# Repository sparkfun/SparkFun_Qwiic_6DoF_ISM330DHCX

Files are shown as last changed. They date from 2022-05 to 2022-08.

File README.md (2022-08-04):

SparkFun Qwiic 6DoF ISM330DHCX
========================================

<table class="table table-hover table-striped table-bordered">
  <tr align="center">
   <td><a href="https://www.sparkfun.com/products/19764">SparkFun Qwiic 6DoF - ISM330DHCX (SEN-19764)</a></td>
   <td><a href="https://www.sparkfun.com/products/20176">SparkFun Micro 6DoF IMU - ISM330DHCX (Qwiic) (SEN-20176</a></td>
  </tr>
  <tr align="center">
   <td><i>SparkFun Qwiic 6DoF - ISM330DHCX [<a href="https://www.sparkfun.com/products/19764">SEN-19764</a>]</i></td>
   <td><i>SparkFun Micro 6DoF IMU - ISM330DHCX (Qwiic) [<a href="https://www.sparkfun.com/products/20176">SEN-20176</a>]</i></td>
  </tr>
</table>

Do you need 6 degrees of freedom? We do! Behold the SparkFun Qwiic 6DoF - ISM330DHCX - a Qwiic enabled 1x1" breakout featuring STMicroelectronics' ISM330DHCX; a high-performance 3D digital accelerometer and 3D digital gyroscope tailored for Industry 4.0 applications such as platform, optical image, and lens stabilization, robotics and industrial automation, navigations systems, and vibration monitoring and compensation. 

This bad boy has a full-scale acceleration range of ±2/±4/±8/±16 g and a wide angular rate range of ±125/±250/±500/±1000/±2000/±4000 dps that enable its usage in a broad range of applications. Multiple modes allow for peripheral only, secondary I<sup>2</sup>C, and and auxiliary 3 or 4 wire serial interface. An unmatched set of embedded features (Machine Learning Core, programmable FSM, FIFO, sensor hub, event decoding and interrupts) are enablers for implementing smart and complex sensor nodes which deliver high performance at very low power.  

The dual Qwiic connectors on this little breakout make setting it up a breeze. Simply supply the accelerometer with power and communication via the Qwiic connector to your chosen Qwiic development board and you will be good to go. Should you prefer to use them, we've also broken out all the ISM330DHCX pin functionality to GPIO along either side of the board. 

Repository Contents
-------------------

* **/Documentation** - Data sheets, additional product information
* **/Hardware** - Eagle design files (.brd, .sch)
* **/Production** - Production panel files (.brd)

Documentation
--------------

* **[Library](https://github.com/sparkfun/SparkFun_6DoF_ISM330DHCX_Arduino_Library)** - Arduino library for the SparkFun Qwiic 6DoF - ISM330DHCX.
* **[Hookup Guide](https://sparkle.sparkfun.com/sparkle/learn_tutorials/2484)** - Basic hookup guide for the SparkFun Qwiic 6DoF - ISM330DHCX.

Product Versions
--------------

* [SEN-20176](https://www.sparkfun.com/products/20176) - SparkFun red version, micro size
* [SEN-19764](https://www.sparkfun.com/products/19764) - SparkFun red version

License Information
-------------------

This product is _**open source**_! 

Please review the LICENSE.md file for license information. 

If you have any questions or concerns on licensing, please contact technical support on our [SparkFun forums](https://forum.sparkfun.com/viewforum.php?f=152).

Distributed as-is; no warranty is given.

- Your friends at SparkFun.

_<COLLABORATION CREDIT>_

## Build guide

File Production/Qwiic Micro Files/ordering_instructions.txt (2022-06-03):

panel size, 170x79mm
PCB thickness, 1.6mm
number of layers, 2
soldermask color, Red
silkscreen color, White
oz copper, 1oz
finish, HASL lead free
stencils, top
pcs per panel, 64
min trace width, 0.1524mm / 0.0060in
min drill size, 0.3000mm / 0.0118in

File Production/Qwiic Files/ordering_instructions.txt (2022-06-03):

panel size, 169x117mm
PCB thickness, 1.6mm
number of layers, 2
soldermask color, Red
silkscreen color, White
oz copper, 1oz
finish, HASL lead free
stencils, top
pcs per panel, 24
min trace width, 0.2540mm / 0.0100in
min drill size, 0.3000mm / 0.0118in

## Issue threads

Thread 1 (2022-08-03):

SparkFun Micro 6DoF IMU - ISM330DHCX (Qwiic): adding "stamp type" pins? (general for all micro boards)

jerabaul29, 2022-08-03:
Thanks for amazing boards as usual :) . A small thought: would it be possible to actually break out the key pins on the chip (power, I2C, maybe interrupts and a couple more, you can evaluate which may be most valuable for different uses :) ) on the breakout board, possibly as "side stamp type pins" if there is no space to put through holes pin holes? I.e., something similar to for example:

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

This comment would be applicable to all "Micro" breakouts. The advantage then is that the "Micro" boards could also be soldered on a master PCB easily if wanted, extending possibilities of use.

edspark, 2022-08-03:
Thank you for the suggestion! We had a discussion while developing the Qwiic Micro about exactly this. We decided against it in the end, but if we see a strong desire for this addition we'll definitely revisit it.

jerabaul29, 2022-08-03:
Thanks for the explanation :) . Just curious, what were the cons Vs pros on this? I only see pros, but certainly missing something :) .

edspark, 2022-08-03:
We wanted the smallest board we could manage and those castellated leads ("side stamp type pins" as you called them) eat into the design space quite a bit.  We would have ended up with a larger PCB then we were shooting for.

jerabaul29, 2022-08-03:
Understand, thanks :) .

Closed 2022-08-03.

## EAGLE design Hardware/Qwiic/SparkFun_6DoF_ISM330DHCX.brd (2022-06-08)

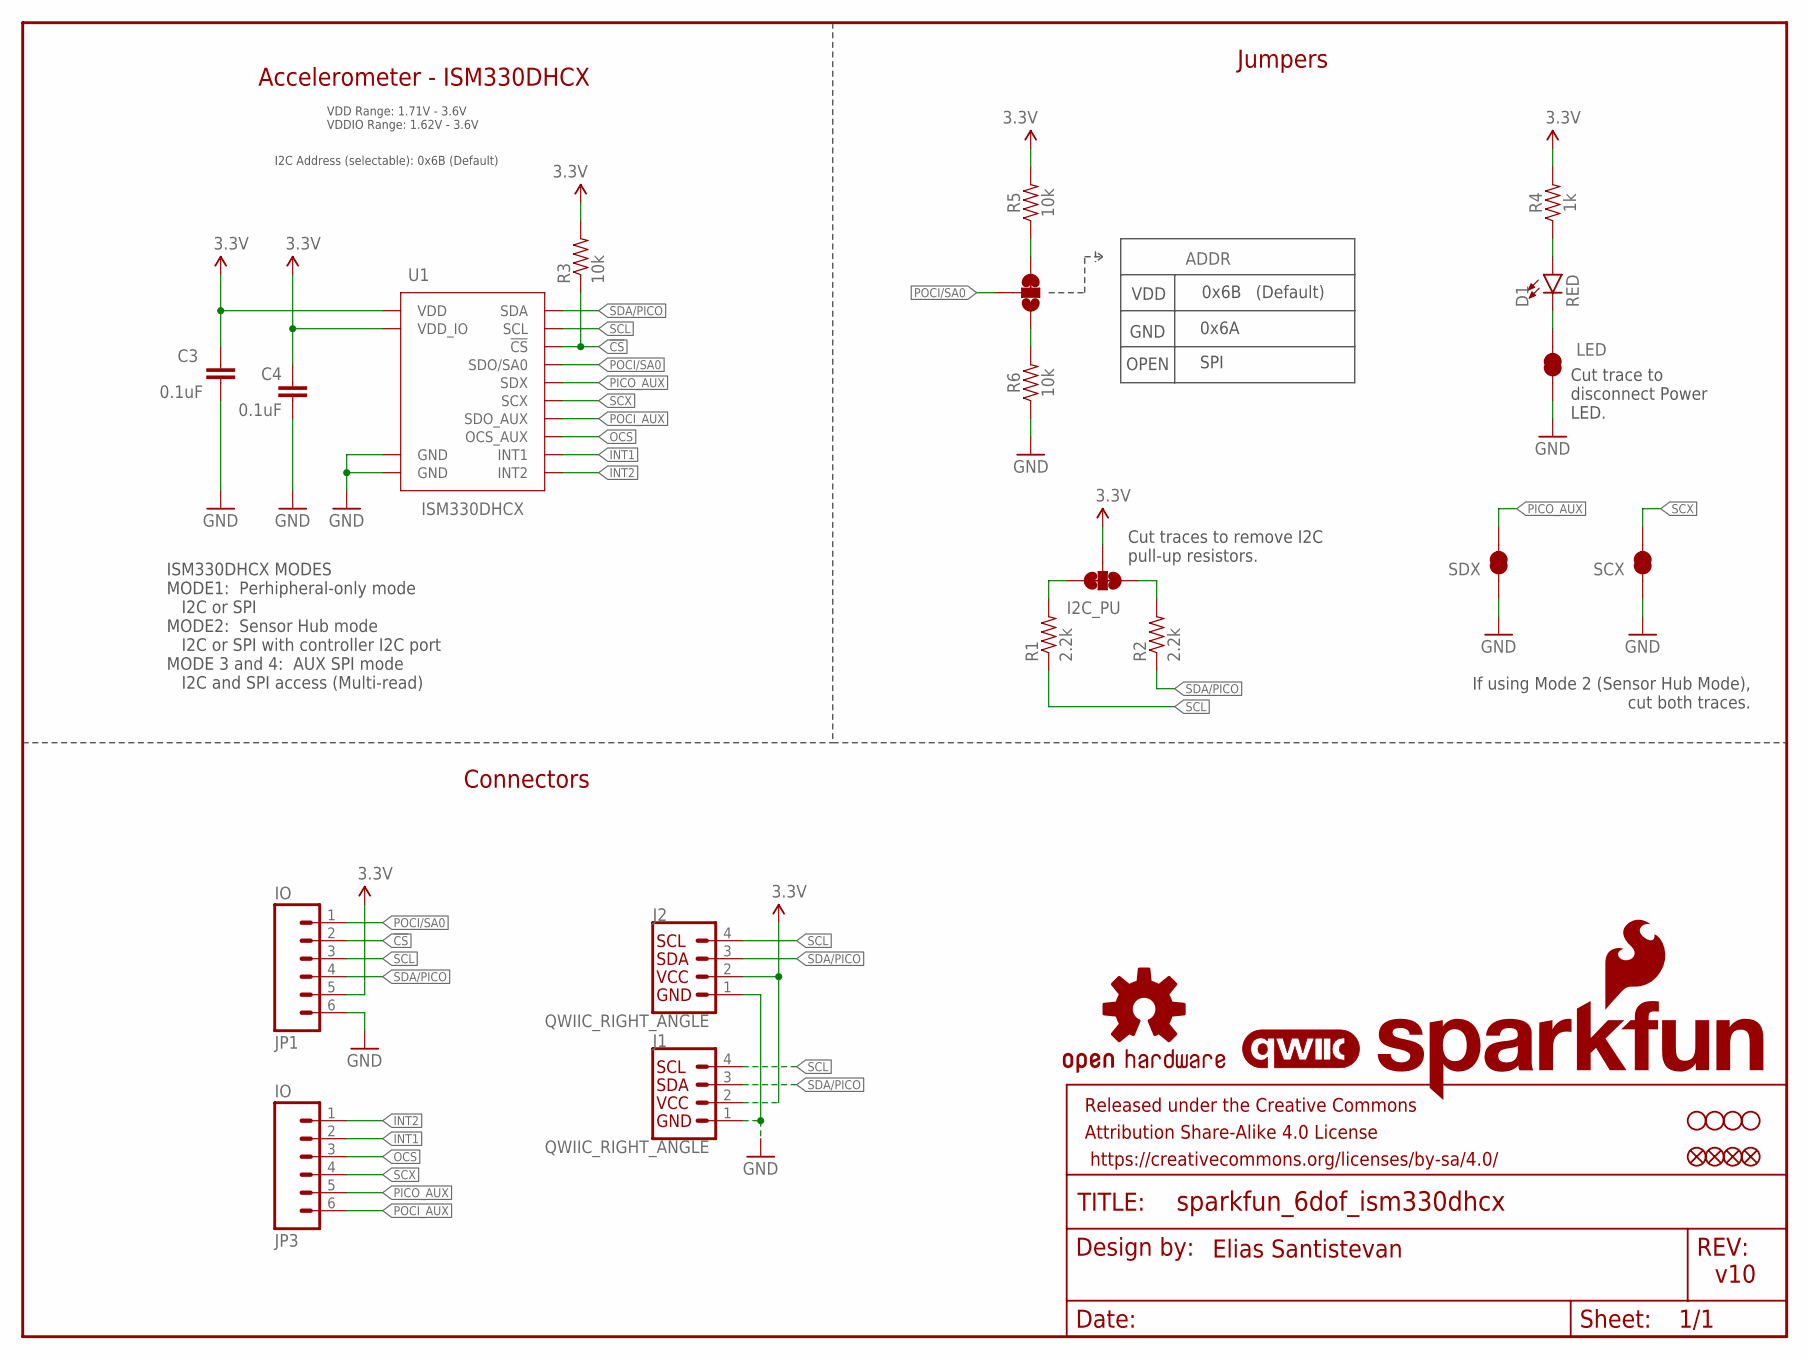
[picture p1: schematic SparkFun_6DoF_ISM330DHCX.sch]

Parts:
ADDR: JUMPER-SMT_3_1-NC_TRACE_SILK; SMT-JUMPER_3_1-NC_TRACE_SILK
C3, C4: 0.1uF; 0603
D1: RED; LED-0603
FD1, FD2: FIDUCIALUFIDUCIAL; FIDUCIAL-MICRO
FID1, FID2: FIDUCIALUFIDUCIAL; FIDUCIAL-MICRO
FRAME1: FRAME-LETTER; CREATIVE_COMMONS
I2C_PU: S_MODE; SMT-JUMPER_3_2-NC_TRACE_SILK
J1, J2: QWIIC_RIGHT_ANGLE; JST04_1MM_RA
JP1, JP3: IO; 1X06_NO_SILK
LED: JUMPER-SMT_2_NC_TRACE_SILK; SMT-JUMPER_2_NC_TRACE_SILK
LOGO1: QWIIC_LOGO_4MM; QWIIC_4MM
LOGO2: OSHW-LOGOMINI; OSHW-LOGO-MINI
LOGO3: SFE_LOGO_NAME_FLAME.1_INCH; SFE_LOGO_NAME_FLAME_.1
R1, R2: 2.2k; 0603
R3, R5, R6: 10k; 0603
R4: 1k; 0603
SCX: JUMPER-SMT_2_NC_TRACE_SILK; SMT-JUMPER_2_NC_TRACE_SILK
SDX: JUMPER-SMT_2_NC_TRACE_SILK; SMT-JUMPER_2_NC_TRACE_SILK
STANDOFF1, STANDOFF2, STANDOFF3, STANDOFF4: STAND-OFFTIGHT; STAND-OFF-TIGHT
U1: ISM330DHCX; LGA-14L

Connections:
3.3V: C3.1, C4.1, I2C_PU.2, J1.2, J2.2, JP1.5, R3.2, R4.2, R5.2, U1.P5 (VDD_IO), U1.P8 (VDD)
!CS!: JP1.2, R3.1, U1.P12 (!CS!)
GND: C3.2, C4.2, J1.1, J2.1, JP1.6, LED.1, R6.1, SCX.1, SDX.1, U1.P6 (GND), U1.P7 (GND)
INT1: JP3.2, U1.P4 (INT1)
INT2: JP3.1, U1.P9 (INT2)
unnamed: ADDR.3, R5.1
unnamed: D1.A, R4.1
unnamed: D1.C, LED.2
unnamed: I2C_PU.1, R1.2
unnamed: I2C_PU.3, R2.2
unnamed: ADDR.1, R6.2
OCS: JP3.3, U1.P10 (OCS_AUX)
PICO_AUX: JP3.5, SDX.2, U1.P2 (SDX)
POCI/SA0: ADDR.2, JP1.1, U1.P1 (SDO/SA0)
POCI_AUX: JP3.6, U1.P11 (SDO_AUX)
SCL: J1.4, J2.4, JP1.3, R1.1, U1.P13 (SCL)
SCX: JP3.4, SCX.2, U1.P3 (SCX)
SDA/PICO: J1.3, J2.3, JP1.4, R2.1, U1.P14 (SDA)

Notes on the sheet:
Accelerometer - ISM330DHCX
If using Mode 2 (Sensor Hub Mode), cut both traces.
Cut traces to remove I2C pull-up resistors.
ISM330DHCX MODES MODE1: Perhipheral-only mode I2C or SPI MODE2: Sensor Hub mode I2C or SPI with controller I2C port MODE 3 and 4: AUX SPI mode I2C and SPI access (Multi-read)
VDD Range: 1.71V - 3.6V VDDIO Range: 1.62V - 3.6V
v10
Jumpers
Cut trace to disconnect Power LED.
Connectors
VDD
GND
OPEN
0x6B
0x6A
SPI
Elias Santistevan
(Default)
I2C Address (selectable): 0x6B (Default)

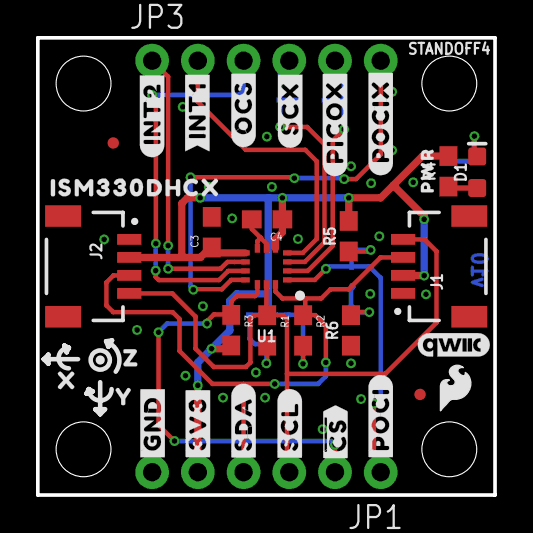
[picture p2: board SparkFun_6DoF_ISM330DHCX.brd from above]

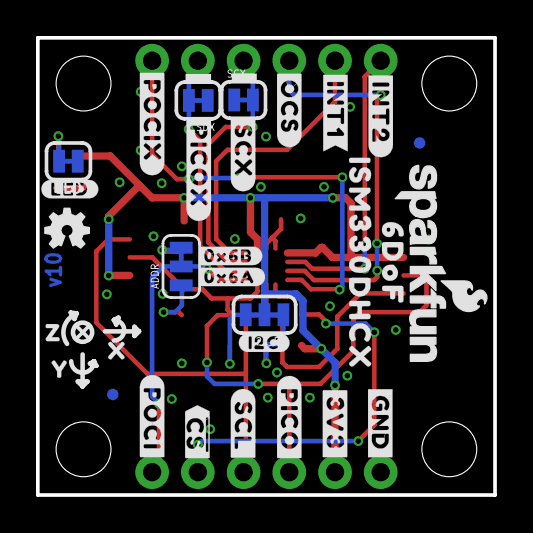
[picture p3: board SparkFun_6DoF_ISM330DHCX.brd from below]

Board: 2 copper layers, 25.4 x 25.4 mm, 70 parts (30 on the bottom side), 18 nets.

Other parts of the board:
U$1, U$15: #3V3#1
U$2, U$17: #GND#0
U$3: ##CS##7
U$4: #SDA#4
U$5, U$22: #SCL#5
U$6: #POCI#11
U$7, U$19: #INT1#9
U$8: #INT2#2
U$9: #OCS#8
U$10: #SCX#9
U$11: #PICOX#10
U$12: ISM330DHCX331
U$13: #0X6A#11
U$14: #0X6B#11
U$16: #LED#11
U$18: #POCI#12
U$20: #OCS#7
U$23: #SCX#8
U$24: #POCIX#8
U$25: #I2C#11
U$26: #PICO#13
U$27: ##CS##8
U$28: PWR8
U$29: SFE_LOGO_FLAME_.1
U$30: ISM330DHCX20
U$31: 6DOF12
U$32: #PICOX#9
U$33: #POCIX#7
U$34, U$37: X2114
U$35, U$38: Y2115
U$36, U$39: Z2116
U$40: #INT2#3

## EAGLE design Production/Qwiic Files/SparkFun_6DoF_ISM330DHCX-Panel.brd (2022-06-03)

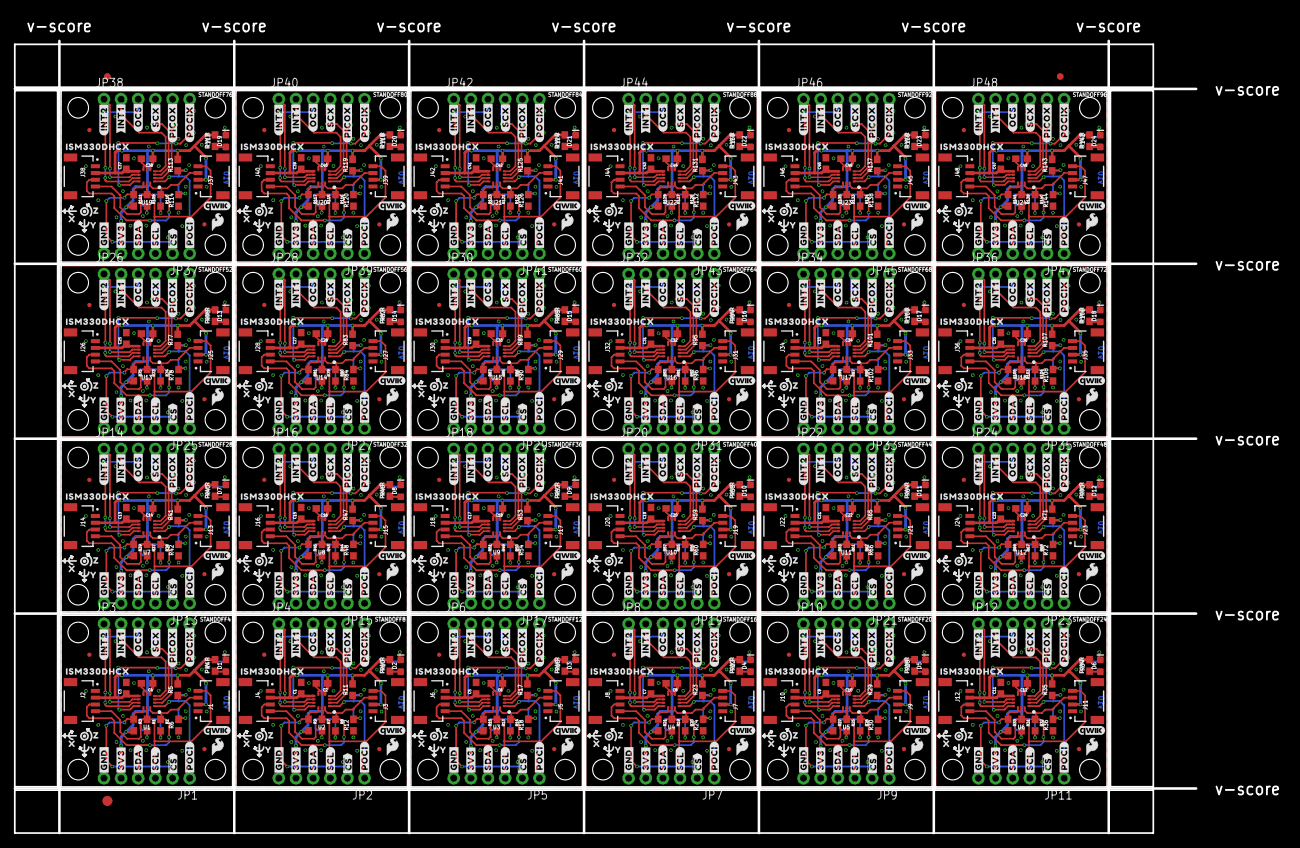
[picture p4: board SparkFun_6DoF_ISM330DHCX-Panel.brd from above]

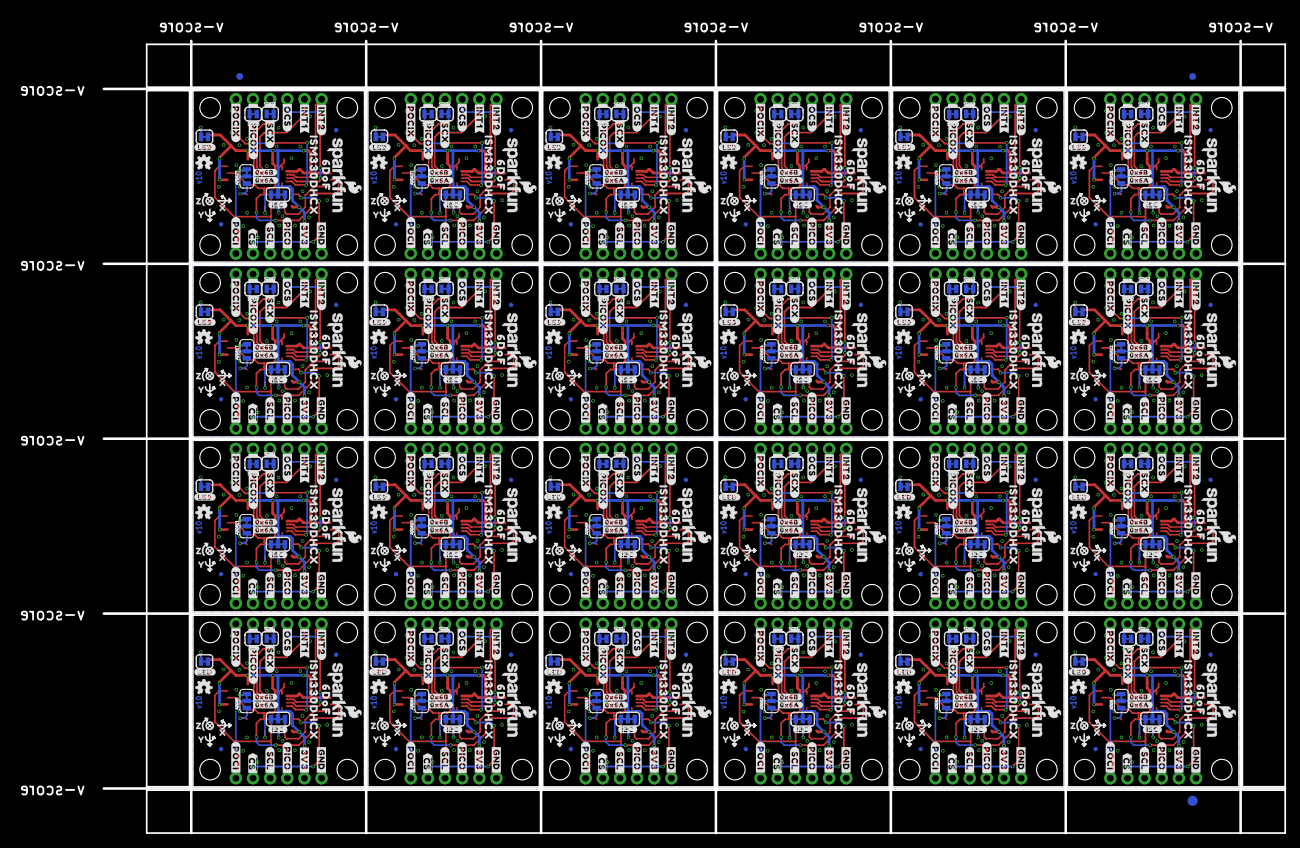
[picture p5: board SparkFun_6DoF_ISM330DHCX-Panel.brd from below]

Board: 2 copper layers, 175.0 x 117.3 mm, 1662 parts (723 on the bottom side), 432 nets.

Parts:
ADDR, ADDR1, ADDR2, ADDR3, ADDR4, ADDR5, ADDR6, ADDR7, ADDR8, ADDR9, ADDR10, ADDR11, ADDR12, ADDR13, ADDR14, ADDR15, ADDR16, ADDR17, ADDR18, ADDR19, ADDR20, ADDR21, ADDR22, ADDR23: JUMPER-SMT_3_1-NC_TRACE_SILK; SMT-JUMPER_3_1-NC_TRACE_SILK
C1, C2, C3, C4, C5, C6, C7, C8, C9, C10, C11, C12, C13, C14, C15, C16, C17, C18, C19, C20, C21, C22, C23, C24, C25, C26, C27, C28, C29, C30, C31, C32, C33, C34, C35, C36, C37, C38, C39, C40, C41, C42, C43, C44, C45, C46, C47, C48: 0.1uF; 0603
D1, D2, D3, D4, D5, D6, D7, D8, D9, D10, D11, D12, D13, D14, D15, D16, D17, D18, D19, D20, D21, D22, D23, D24: RED; LED-0603
E$1, E$2, E$3, E$4: FIDUCIAL-1X2
E$5, E$6: FIDUCIAL-1.5X3
FD1, FD2, FD3, FD4, FD5, FD6, FD7, FD8, FD9, FD10, FD11, FD12, FD13, FD14, FD15, FD16, FD17, FD18, FD19, FD20, FD21, FD22, FD23, FD24, FD25, FD26, FD27, FD28, FD29, FD30, FD31, FD32, FD33, FD34, FD35, FD36, FD37, FD38, FD39, FD40, FD41, FD42, FD43, FD44, FD45, FD46, FD47, FD48: FIDUCIALUFIDUCIAL; FIDUCIAL-MICRO
FID1, FID2, FID3, FID4, FID5, FID6, FID7, FID8, FID9, FID10, FID11, FID12, FID13, FID14, FID15, FID16, FID17, FID18, FID19, FID20, FID21, FID22, FID23, FID24, FID25, FID26, FID27, FID28, FID29, FID30, FID31, FID32, FID33, FID34, FID35, FID36, FID37, FID38, FID39, FID40, FID41, FID42, FID43, FID44, FID45, FID46, FID47, FID48: FIDUCIALUFIDUCIAL; FIDUCIAL-MICRO
I2C_PU, I2C_PU1, I2C_PU2, I2C_PU3, I2C_PU4, I2C_PU5, I2C_PU6, I2C_PU7, I2C_PU8, I2C_PU9, I2C_PU10, I2C_PU11, I2C_PU12, I2C_PU13, I2C_PU14, I2C_PU15, I2C_PU16, I2C_PU17, I2C_PU18, I2C_PU19, I2C_PU20, I2C_PU21, I2C_PU22, I2C_PU23: S_MODE; SMT-JUMPER_3_2-NC_TRACE_SILK
J1, J2, J3, J4, J5, J6, J7, J8, J9, J10, J11, J12, J13, J14, J15, J16, J17, J18, J19, J20, J21, J22, J23, J24, J25, J26, J27, J28, J29, J30, J31, J32, J33, J34, J35, J36, J37, J38, J39, J40, J41, J42, J43, J44, J45, J46, J47, J48: QWIIC_RIGHT_ANGLE; JST04_1MM_RA
JP1, JP2, JP3, JP4, JP5, JP6, JP7, JP8, JP9, JP10, JP11, JP12, JP13, JP14, JP15, JP16, JP17, JP18, JP19, JP20, JP21, JP22, JP23, JP24, JP25, JP26, JP27, JP28, JP29, JP30, JP31, JP32, JP33, JP34, JP35, JP36, JP37, JP38, JP39, JP40, JP41, JP42, JP43, JP44, JP45, JP46, JP47, JP48: IO; 1X06_NO_SILK
LED, LED1, LED2, LED3, LED4, LED5, LED6, LED7, LED8, LED9, LED10, LED11, LED12, LED13, LED14, LED15, LED16, LED17, LED18, LED19, LED20, LED21, LED22, LED23: JUMPER-SMT_2_NC_TRACE_SILK; SMT-JUMPER_2_NC_TRACE_SILK
LOGO1, LOGO6, LOGO9, LOGO12, LOGO15, LOGO18, LOGO21, LOGO24, LOGO27, LOGO30, LOGO33, LOGO36, LOGO39, LOGO42, LOGO45, LOGO48, LOGO51, LOGO54, LOGO57, LOGO60, LOGO63, LOGO66, LOGO69, LOGO72: QWIIC_LOGO_4MM; QWIIC_4MM
LOGO2, LOGO4, LOGO7, LOGO10, LOGO13, LOGO16, LOGO19, LOGO22, LOGO25, LOGO28, LOGO31, LOGO34, LOGO37, LOGO40, LOGO43, LOGO46, LOGO49, LOGO52, LOGO55, LOGO58, LOGO61, LOGO64, LOGO67, LOGO70: OSHW-LOGOMINI; OSHW-LOGO-MINI
LOGO3, LOGO5, LOGO8, LOGO11, LOGO14, LOGO17, LOGO20, LOGO23, LOGO26, LOGO29, LOGO32, LOGO35, LOGO38, LOGO41, LOGO44, LOGO47, LOGO50, LOGO53, LOGO56, LOGO59, LOGO62, LOGO65, LOGO68, LOGO71: SFE_LOGO_NAME_FLAME.1_INCH; SFE_LOGO_NAME_FLAME_.1
R1, R2, R7, R8, R13, R14, R19, R20, R25, R26, R31, R32, R37, R38, R43, R44, R49, R50, R55, R56, R61, R62, R67, R68, R73, R74, R79, R80, R85, R86, R91, R92, R97, R98, R103, R104, R109, R110, R115, R116, R121, R122, R127, R128, R133, R134, R139, R140: 2.2k; 0603
R3, R5, R6, R9, R11, R12, R15, R17, R18, R21, R23, R24, R27, R29, R30, R33, R35, R36, R39, R41, R42, R45, R47, R48, R51, R53, R54, R57, R59, R60, R63, R65, R66, R69, R71, R72, R75, R77, R78, R81, R83, R84, R87, R89, R90, R93, R95, R96, R99, R101, R102, R105, R107, R108, R111, R113, R114, R117, R119, R120, R123, R125, R126, R129, R131, R132, R135, R137, R138, R141, R143, R144: 10k; 0603
R4, R10, R16, R22, R28, R34, R40, R46, R52, R58, R64, R70, R76, R82, R88, R94, R100, R106, R112, R118, R124, R130, R136, R142: 1k; 0603
SCX, SCX1, SCX2, SCX3, SCX4, SCX5, SCX6, SCX7, SCX8, SCX9, SCX10, SCX11, SCX12, SCX13, SCX14, SCX15, SCX16, SCX17, SCX18, SCX19, SCX20, SCX21, SCX22, SCX23: JUMPER-SMT_2_NC_TRACE_SILK; SMT-JUMPER_2_NC_TRACE_SILK
SDX, SDX1, SDX2, SDX3, SDX4, SDX5, SDX6, SDX7, SDX8, SDX9, SDX10, SDX11, SDX12, SDX13, SDX14, SDX15, SDX16, SDX17, SDX18, SDX19, SDX20, SDX21, SDX22, SDX23: JUMPER-SMT_2_NC_TRACE_SILK; SMT-JUMPER_2_NC_TRACE_SILK
STANDOFF1, STANDOFF2, STANDOFF3, STANDOFF4, STANDOFF5, STANDOFF6, STANDOFF7, STANDOFF8, STANDOFF9, STANDOFF10, STANDOFF11, STANDOFF12, STANDOFF13, STANDOFF14, STANDOFF15, STANDOFF16, STANDOFF17, STANDOFF18, STANDOFF19, STANDOFF20, STANDOFF21, STANDOFF22, STANDOFF23, STANDOFF24, STANDOFF25, STANDOFF26, STANDOFF27, STANDOFF28, STANDOFF29, STANDOFF30, STANDOFF31, STANDOFF32, STANDOFF33, STANDOFF34, STANDOFF35, STANDOFF36, STANDOFF37, STANDOFF38, STANDOFF39, STANDOFF40, STANDOFF41, STANDOFF42, STANDOFF43, STANDOFF44, STANDOFF45, STANDOFF46, STANDOFF47, STANDOFF48, STANDOFF49, STANDOFF50, STANDOFF51, STANDOFF52, STANDOFF53, STANDOFF54, STANDOFF55, STANDOFF56, STANDOFF57, STANDOFF58, STANDOFF59, STANDOFF60, STANDOFF61, STANDOFF62, STANDOFF63, STANDOFF64, STANDOFF65, STANDOFF66, STANDOFF67, STANDOFF68, STANDOFF69, STANDOFF70, STANDOFF71, STANDOFF72, STANDOFF73, STANDOFF74, STANDOFF75, STANDOFF76, STANDOFF77, STANDOFF78, STANDOFF79, STANDOFF80, STANDOFF81, STANDOFF82, STANDOFF83, STANDOFF84, STANDOFF85, STANDOFF86, STANDOFF87, STANDOFF88, STANDOFF89, STANDOFF90, STANDOFF91, STANDOFF92, STANDOFF93, STANDOFF94, STANDOFF95, STANDOFF96: STAND-OFFTIGHT; STAND-OFF-TIGHT
U1, U2, U3, U4, U5, U6, U7, U8, U9, U10, U11, U12, U13, U14, U15, U16, U17, U18, U19, U20, U21, U22, U23, U24: ISM330DHCX; LGA-14L
U$1, U$15, U$21, U$46, U$79, U$85, U$118, U$124, U$157, U$163, U$196, U$202, U$235, U$241, U$274, U$280, U$313, U$319, U$352, U$358, U$391, U$397, U$430, U$436, U$469, U$475, U$508, U$514, U$547, U$553, U$586, U$592, U$625, U$631, U$664, U$670, U$703, U$709, U$742, U$748, U$781, U$787, U$820, U$826, U$859, U$865, U$898, U$904: #3V3#1
U$2, U$17, U$41, U$47, U$80, U$86, U$119, U$125, U$158, U$164, U$197, U$203, U$236, U$242, U$275, U$281, U$314, U$320, U$353, U$359, U$392, U$398, U$431, U$437, U$470, U$476, U$509, U$515, U$548, U$554, U$587, U$593, U$626, U$632, U$665, U$671, U$704, U$710, U$743, U$749, U$782, U$788, U$821, U$827, U$860, U$866, U$899, U$905: #GND#0
U$3, U$58, U$97, U$136, U$175, U$214, U$253, U$292, U$331, U$370, U$409, U$448, U$487, U$526, U$565, U$604, U$643, U$682, U$721, U$760, U$799, U$838, U$877, U$916: ##CS##7
U$4, U$42, U$81, U$120, U$159, U$198, U$237, U$276, U$315, U$354, U$393, U$432, U$471, U$510, U$549, U$588, U$627, U$666, U$705, U$744, U$783, U$822, U$861, U$900: #SDA#4
U$5, U$22, U$43, U$49, U$82, U$88, U$121, U$127, U$160, U$166, U$199, U$205, U$238, U$244, U$277, U$283, U$316, U$322, U$355, U$361, U$394, U$400, U$433, U$439, U$472, U$478, U$511, U$517, U$550, U$556, U$589, U$595, U$628, U$634, U$667, U$673, U$706, U$712, U$745, U$751, U$784, U$790, U$823, U$829, U$862, U$868, U$901, U$907: #SCL#5
U$6, U$69, U$108, U$147, U$186, U$225, U$264, U$303, U$342, U$381, U$420, U$459, U$498, U$537, U$576, U$615, U$654, U$693, U$732, U$771, U$810, U$849, U$888, U$927: #POCI#11
U$7, U$19, U$56, U$57, U$95, U$96, U$134, U$135, U$173, U$174, U$212, U$213, U$251, U$252, U$290, U$291, U$329, U$330, U$368, U$369, U$407, U$408, U$446, U$447, U$485, U$486, U$524, U$525, U$563, U$564, U$602, U$603, U$641, U$642, U$680, U$681, U$719, U$720, U$758, U$759, U$797, U$798, U$836, U$837, U$875, U$876, U$914, U$915: #INT1#9
U$8, U$78, U$117, U$156, U$195, U$234, U$273, U$312, U$351, U$390, U$429, U$468, U$507, U$546, U$585, U$624, U$663, U$702, U$741, U$780, U$819, U$858, U$897, U$936: #INT2#2
U$9, U$44, U$83, U$122, U$161, U$200, U$239, U$278, U$317, U$356, U$395, U$434, U$473, U$512, U$551, U$590, U$629, U$668, U$707, U$746, U$785, U$824, U$863, U$902: #OCS#8
U$10, U$45, U$84, U$123, U$162, U$201, U$240, U$279, U$318, U$357, U$396, U$435, U$474, U$513, U$552, U$591, U$630, U$669, U$708, U$747, U$786, U$825, U$864, U$903: #SCX#9
U$11, U$64, U$103, U$142, U$181, U$220, U$259, U$298, U$337, U$376, U$415, U$454, U$493, U$532, U$571, U$610, U$649, U$688, U$727, U$766, U$805, U$844, U$883, U$922: #PICOX#10
U$12, U$62, U$101, U$140, U$179, U$218, U$257, U$296, U$335, U$374, U$413, U$452, U$491, U$530, U$569, U$608, U$647, U$686, U$725, U$764, U$803, U$842, U$881, U$920: ISM330DHCX331
U$13, U$52, U$91, U$130, U$169, U$208, U$247, U$286, U$325, U$364, U$403, U$442, U$481, U$520, U$559, U$598, U$637, U$676, U$715, U$754, U$793, U$832, U$871, U$910: #0X6A#11
U$14, U$53, U$92, U$131, U$170, U$209, U$248, U$287, U$326, U$365, U$404, U$443, U$482, U$521, U$560, U$599, U$638, U$677, U$716, U$755, U$794, U$833, U$872, U$911: #0X6B#11
U$16, U$51, U$90, U$129, U$168, U$207, U$246, U$285, U$324, U$363, U$402, U$441, U$480, U$519, U$558, U$597, U$636, U$675, U$714, U$753, U$792, U$831, U$870, U$909: #LED#11
U$18, U$70, U$109, U$148, U$187, U$226, U$265, U$304, U$343, U$382, U$421, U$460, U$499, U$538, U$577, U$616, U$655, U$694, U$733, U$772, U$811, U$850, U$889, U$928: #POCI#12
U$20, U$48, U$87, U$126, U$165, U$204, U$243, U$282, U$321, U$360, U$399, U$438, U$477, U$516, U$555, U$594, U$633, U$672, U$711, U$750, U$789, U$828, U$867, U$906: #OCS#7
U$23, U$50, U$89, U$128, U$167, U$206, U$245, U$284, U$323, U$362, U$401, U$440, U$479, U$518, U$557, U$596, U$635, U$674, U$713, U$752, U$791, U$830, U$869, U$908: #SCX#8
U$24, U$65, U$104, U$143, U$182, U$221, U$260, U$299, U$338, U$377, U$416, U$455, U$494, U$533, U$572, U$611, U$650, U$689, U$728, U$767, U$806, U$845, U$884, U$923: #POCIX#8
U$25, U$54, U$93, U$132, U$171, U$210, U$249, U$288, U$327, U$366, U$405, U$444, U$483, U$522, U$561, U$600, U$639, U$678, U$717, U$756, U$795, U$834, U$873, U$912: #I2C#11
U$26, U$68, U$107, U$146, U$185, U$224, U$263, U$302, U$341, U$380, U$419, U$458, U$497, U$536, U$575, U$614, U$653, U$692, U$731, U$770, U$809, U$848, U$887, U$926: #PICO#13
U$27, U$59, U$98, U$137, U$176, U$215, U$254, U$293, U$332, U$371, U$410, U$449, U$488, U$527, U$566, U$605, U$644, U$683, U$722, U$761, U$800, U$839, U$878, U$917: ##CS##8
U$28, U$55, U$94, U$133, U$172, U$211, U$250, U$289, U$328, U$367, U$406, U$445, U$484, U$523, U$562, U$601, U$640, U$679, U$718, U$757, U$796, U$835, U$874, U$913: PWR8
U$29, U$61, U$100, U$139, U$178, U$217, U$256, U$295, U$334, U$373, U$412, U$451, U$490, U$529, U$568, U$607, U$646, U$685, U$724, U$763, U$802, U$841, U$880, U$919: SFE_LOGO_FLAME_.1
U$30, U$63, U$102, U$141, U$180, U$219, U$258, U$297, U$336, U$375, U$414, U$453, U$492, U$531, U$570, U$609, U$648, U$687, U$726, U$765, U$804, U$843, U$882, U$921: ISM330DHCX20
U$31, U$60, U$99, U$138, U$177, U$216, U$255, U$294, U$333, U$372, U$411, U$450, U$489, U$528, U$567, U$606, U$645, U$684, U$723, U$762, U$801, U$840, U$879, U$918: 6DOF12
U$32, U$66, U$105, U$144, U$183, U$222, U$261, U$300, U$339, U$378, U$417, U$456, U$495, U$534, U$573, U$612, U$651, U$690, U$729, U$768, U$807, U$846, U$885, U$924: #PICOX#9
U$33, U$67, U$106, U$145, U$184, U$223, U$262, U$301, U$340, U$379, U$418, U$457, U$496, U$535, U$574, U$613, U$652, U$691, U$730, U$769, U$808, U$847, U$886, U$925: #POCIX#7
U$34, U$37, U$71, U$74, U$110, U$113, U$149, U$152, U$188, U$191, U$227, U$230, U$266, U$269, U$305, U$308, U$344, U$347, U$383, U$386, U$422, U$425, U$461, U$464, U$500, U$503, U$539, U$542, U$578, U$581, U$617, U$620, U$656, U$659, U$695, U$698, U$734, U$737, U$773, U$776, U$812, U$815, U$851, U$854, U$890, U$893, U$929, U$932: X2114
U$35, U$38, U$72, U$75, U$111, U$114, U$150, U$153, U$189, U$192, U$228, U$231, U$267, U$270, U$306, U$309, U$345, U$348, U$384, U$387, U$423, U$426, U$462, U$465, U$501, U$504, U$540, U$543, U$579, U$582, U$618, U$621, U$657, U$660, U$696, U$699, U$735, U$738, U$774, U$777, U$813, U$816, U$852, U$855, U$891, U$894, U$930, U$933: Y2115
U$36, U$39, U$73, U$76, U$112, U$115, U$151, U$154, U$190, U$193, U$229, U$232, U$268, U$271, U$307, U$310, U$346, U$349, U$385, U$388, U$424, U$427, U$463, U$466, U$502, U$505, U$541, U$544, U$580, U$583, U$619, U$622, U$658, U$661, U$697, U$700, U$736, U$739, U$775, U$778, U$814, U$817, U$853, U$856, U$892, U$895, U$931, U$934: Z2116
U$40, U$77, U$116, U$155, U$194, U$233, U$272, U$311, U$350, U$389, U$428, U$467, U$506, U$545, U$584, U$623, U$662, U$701, U$740, U$779, U$818, U$857, U$896, U$935: #INT2#3

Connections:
3.3V: C3.1, C4.1, I2C_PU.2, J1.2, J2.2, JP1.5, R3.2, R4.2, R5.2, U1.P5, U1.P8
3.3V1: C1.1, C2.1, I2C_PU1.2, J3.2, J4.2, JP2.5, R9.2, R10.2, R11.2, U2.P5, U2.P8
3.3V2: C5.1, C6.1, I2C_PU2.2, J5.2, J6.2, JP5.5, R15.2, R16.2, R17.2, U3.P5, U3.P8
3.3V3: C7.1, C8.1, I2C_PU3.2, J7.2, J8.2, JP7.5, R21.2, R22.2, R23.2, U4.P5, U4.P8
3.3V4: C9.1, C10.1, I2C_PU4.2, J9.2, J10.2, JP9.5, R27.2, R28.2, R29.2, U5.P5, U5.P8
3.3V5: C11.1, C12.1, I2C_PU5.2, J11.2, J12.2, JP11.5, R33.2, R34.2, R35.2, U6.P5, U6.P8
3.3V6: C13.1, C14.1, I2C_PU6.2, J13.2, J14.2, JP13.5, R39.2, R40.2, R41.2, U7.P5, U7.P8
3.3V7: C15.1, C16.1, I2C_PU7.2, J15.2, J16.2, JP15.5, R45.2, R46.2, R47.2, U8.P5, U8.P8
3.3V8: C17.1, C18.1, I2C_PU8.2, J17.2, J18.2, JP17.5, R51.2, R52.2, R53.2, U9.P5, U9.P8
3.3V9: C19.1, C20.1, I2C_PU9.2, J19.2, J20.2, JP19.5, R57.2, R58.2, R59.2, U10.P5, U10.P8
3.3V10: C21.1, C22.1, I2C_PU10.2, J21.2, J22.2, JP21.5, R63.2, R64.2, R65.2, U11.P5, U11.P8
3.3V11: C23.1, C24.1, I2C_PU11.2, J23.2, J24.2, JP23.5, R69.2, R70.2, R71.2, U12.P5, U12.P8
3.3V12: C25.1, C26.1, I2C_PU12.2, J25.2, J26.2, JP25.5, R75.2, R76.2, R77.2, U13.P5, U13.P8
3.3V13: C27.1, C28.1, I2C_PU13.2, J27.2, J28.2, JP27.5, R81.2, R82.2, R83.2, U14.P5, U14.P8
3.3V14: C29.1, C30.1, I2C_PU14.2, J29.2, J30.2, JP29.5, R87.2, R88.2, R89.2, U15.P5, U15.P8
3.3V15: C31.1, C32.1, I2C_PU15.2, J31.2, J32.2, JP31.5, R93.2, R94.2, R95.2, U16.P5, U16.P8
3.3V16: C33.1, C34.1, I2C_PU16.2, J33.2, J34.2, JP33.5, R99.2, R100.2, R101.2, U17.P5, U17.P8
3.3V17: C35.1, C36.1, I2C_PU17.2, J35.2, J36.2, JP35.5, R105.2, R106.2, R107.2, U18.P5, U18.P8
3.3V18: C37.1, C38.1, I2C_PU18.2, J37.2, J38.2, JP37.5, R111.2, R112.2, R113.2, U19.P5, U19.P8
3.3V19: C39.1, C40.1, I2C_PU19.2, J39.2, J40.2, JP39.5, R117.2, R118.2, R119.2, U20.P5, U20.P8
3.3V20: C41.1, C42.1, I2C_PU20.2, J41.2, J42.2, JP41.5, R123.2, R124.2, R125.2, U21.P5, U21.P8
3.3V21: C43.1, C44.1, I2C_PU21.2, J43.2, J44.2, JP43.5, R129.2, R130.2, R131.2, U22.P5, U22.P8
3.3V22: C45.1, C46.1, I2C_PU22.2, J45.2, J46.2, JP45.5, R135.2, R136.2, R137.2, U23.P5, U23.P8
3.3V23: C47.1, C48.1, I2C_PU23.2, J47.2, J48.2, JP47.5, R141.2, R142.2, R143.2, U24.P5, U24.P8
!CS!: JP1.2, R3.1, U1.P12
!CS!1: JP2.2, R9.1, U2.P12
!CS!2: JP5.2, R15.1, U3.P12
!CS!3: JP7.2, R21.1, U4.P12
!CS!4: JP9.2, R27.1, U5.P12
!CS!5: JP11.2, R33.1, U6.P12
!CS!6: JP13.2, R39.1, U7.P12
!CS!7: JP15.2, R45.1, U8.P12
!CS!8: JP17.2, R51.1, U9.P12
!CS!9: JP19.2, R57.1, U10.P12
!CS!10: JP21.2, R63.1, U11.P12
!CS!11: JP23.2, R69.1, U12.P12
!CS!12: JP25.2, R75.1, U13.P12
!CS!13: JP27.2, R81.1, U14.P12
!CS!14: JP29.2, R87.1, U15.P12
!CS!15: JP31.2, R93.1, U16.P12
!CS!16: JP33.2, R99.1, U17.P12
!CS!17: JP35.2, R105.1, U18.P12
!CS!18: JP37.2, R111.1, U19.P12
!CS!19: JP39.2, R117.1, U20.P12
!CS!20: JP41.2, R123.1, U21.P12
!CS!21: JP43.2, R129.1, U22.P12
!CS!22: JP45.2, R135.1, U23.P12
!CS!23: JP47.2, R141.1, U24.P12
GND: C3.2, C4.2, J1.1, J2.1, JP1.6, LED.1, R6.1, SCX.1, SDX.1, U1.P6, U1.P7
GND1: C1.2, C2.2, J3.1, J4.1, JP2.6, LED1.1, R12.1, SCX1.1, SDX1.1, U2.P6, U2.P7
GND2: C5.2, C6.2, J5.1, J6.1, JP5.6, LED2.1, R18.1, SCX2.1, SDX2.1, U3.P6, U3.P7
GND3: C7.2, C8.2, J7.1, J8.1, JP7.6, LED3.1, R24.1, SCX3.1, SDX3.1, U4.P6, U4.P7
GND4: C9.2, C10.2, J9.1, J10.1, JP9.6, LED4.1, R30.1, SCX4.1, SDX4.1, U5.P6, U5.P7
GND5: C11.2, C12.2, J11.1, J12.1, JP11.6, LED5.1, R36.1, SCX5.1, SDX5.1, U6.P6, U6.P7
GND6: C13.2, C14.2, J13.1, J14.1, JP13.6, LED6.1, R42.1, SCX6.1, SDX6.1, U7.P6, U7.P7
GND7: C15.2, C16.2, J15.1, J16.1, JP15.6, LED7.1, R48.1, SCX7.1, SDX7.1, U8.P6, U8.P7
GND8: C17.2, C18.2, J17.1, J18.1, JP17.6, LED8.1, R54.1, SCX8.1, SDX8.1, U9.P6, U9.P7
GND9: C19.2, C20.2, J19.1, J20.1, JP19.6, LED9.1, R60.1, SCX9.1, SDX9.1, U10.P6, U10.P7
GND10: C21.2, C22.2, J21.1, J22.1, JP21.6, LED10.1, R66.1, SCX10.1, SDX10.1, U11.P6, U11.P7
GND11: C23.2, C24.2, J23.1, J24.1, JP23.6, LED11.1, R72.1, SCX11.1, SDX11.1, U12.P6, U12.P7
GND12: C25.2, C26.2, J25.1, J26.1, JP25.6, LED12.1, R78.1, SCX12.1, SDX12.1, U13.P6, U13.P7
GND13: C27.2, C28.2, J27.1, J28.1, JP27.6, LED13.1, R84.1, SCX13.1, SDX13.1, U14.P6, U14.P7
GND14: C29.2, C30.2, J29.1, J30.1, JP29.6, LED14.1, R90.1, SCX14.1, SDX14.1, U15.P6, U15.P7
GND15: C31.2, C32.2, J31.1, J32.1, JP31.6, LED15.1, R96.1, SCX15.1, SDX15.1, U16.P6, U16.P7
GND16: C33.2, C34.2, J33.1, J34.1, JP33.6, LED16.1, R102.1, SCX16.1, SDX16.1, U17.P6, U17.P7
GND17: C35.2, C36.2, J35.1, J36.1, JP35.6, LED17.1, R108.1, SCX17.1, SDX17.1, U18.P6, U18.P7
GND18: C37.2, C38.2, J37.1, J38.1, JP37.6, LED18.1, R114.1, SCX18.1, SDX18.1, U19.P6, U19.P7
GND19: C39.2, C40.2, J39.1, J40.1, JP39.6, LED19.1, R120.1, SCX19.1, SDX19.1, U20.P6, U20.P7
GND20: C41.2, C42.2, J41.1, J42.1, JP41.6, LED20.1, R126.1, SCX20.1, SDX20.1, U21.P6, U21.P7
GND21: C43.2, C44.2, J43.1, J44.1, JP43.6, LED21.1, R132.1, SCX21.1, SDX21.1, U22.P6, U22.P7
GND22: C45.2, C46.2, J45.1, J46.1, JP45.6, LED22.1, R138.1, SCX22.1, SDX22.1, U23.P6, U23.P7
GND23: C47.2, C48.2, J47.1, J48.1, JP47.6, LED23.1, R144.1, SCX23.1, SDX23.1, U24.P6, U24.P7
INT1: JP3.2, U1.P4
INT2: JP3.1, U1.P9
INT3: JP4.2, U2.P4
INT4: JP4.1, U2.P9
INT5: JP6.2, U3.P4
INT6: JP6.1, U3.P9
INT7: JP8.2, U4.P4
INT8: JP8.1, U4.P9
INT9: JP10.2, U5.P4
INT10: JP10.1, U5.P9
INT11: JP12.2, U6.P4
INT12: JP12.1, U6.P9
INT13: JP14.2, U7.P4
INT14: JP14.1, U7.P9
INT15: JP16.2, U8.P4
INT16: JP16.1, U8.P9
INT17: JP18.2, U9.P4
INT18: JP18.1, U9.P9
INT19: JP20.2, U10.P4
INT20: JP20.1, U10.P9
INT21: JP22.2, U11.P4
INT22: JP22.1, U11.P9
INT23: JP24.2, U12.P4
INT24: JP24.1, U12.P9
INT25: JP26.2, U13.P4
INT26: JP26.1, U13.P9
INT27: JP28.2, U14.P4
INT28: JP28.1, U14.P9
INT29: JP30.2, U15.P4
INT30: JP30.1, U15.P9
INT31: JP32.2, U16.P4
INT32: JP32.1, U16.P9
INT33: JP34.2, U17.P4
INT34: JP34.1, U17.P9
INT35: JP36.2, U18.P4
INT36: JP36.1, U18.P9
INT37: JP38.2, U19.P4
INT38: JP38.1, U19.P9
INT39: JP40.2, U20.P4
INT40: JP40.1, U20.P9
INT41: JP42.2, U21.P4
INT42: JP42.1, U21.P9
INT43: JP44.2, U22.P4
INT44: JP44.1, U22.P9
INT45: JP46.2, U23.P4
INT46: JP46.1, U23.P9
INT47: JP48.2, U24.P4
INT48: JP48.1, U24.P9
unnamed: ADDR.3, R5.1
unnamed: D1.A, R4.1
unnamed: D1.C, LED.2
unnamed: I2C_PU1.1, R7.2
unnamed: I2C_PU.1, R1.2
unnamed: I2C_PU.3, R2.2
unnamed: ADDR.1, R6.2
unnamed: I2C_PU1.3, R8.2
unnamed: D2.A, R10.1
unnamed: D2.C, LED1.2
unnamed: ADDR1.3, R11.1
unnamed: ADDR1.1, R12.2
unnamed: I2C_PU2.1, R13.2
unnamed: I2C_PU2.3, R14.2
unnamed: D3.A, R16.1
unnamed: D3.C, LED2.2
unnamed: ADDR2.3, R17.1
unnamed: ADDR2.1, R18.2
unnamed: I2C_PU3.1, R19.2
unnamed: I2C_PU3.3, R20.2
unnamed: D4.A, R22.1
unnamed: D4.C, LED3.2
unnamed: ADDR3.3, R23.1
unnamed: ADDR3.1, R24.2
unnamed: I2C_PU4.1, R25.2
unnamed: I2C_PU4.3, R26.2
unnamed: D5.A, R28.1
unnamed: D5.C, LED4.2
unnamed: ADDR4.3, R29.1
unnamed: ADDR4.1, R30.2
unnamed: I2C_PU5.1, R31.2
unnamed: I2C_PU5.3, R32.2
unnamed: D6.A, R34.1
unnamed: D6.C, LED5.2
unnamed: ADDR5.3, R35.1
unnamed: ADDR5.1, R36.2
unnamed: I2C_PU6.1, R37.2
unnamed: I2C_PU6.3, R38.2
unnamed: D7.A, R40.1
unnamed: D7.C, LED6.2
unnamed: ADDR6.3, R41.1
unnamed: ADDR6.1, R42.2
unnamed: I2C_PU7.1, R43.2
unnamed: I2C_PU7.3, R44.2
unnamed: D8.A, R46.1
unnamed: D8.C, LED7.2
unnamed: ADDR7.3, R47.1
unnamed: ADDR7.1, R48.2
unnamed: I2C_PU8.1, R49.2
unnamed: I2C_PU8.3, R50.2
unnamed: D9.A, R52.1
unnamed: D9.C, LED8.2
unnamed: ADDR8.3, R53.1
unnamed: ADDR8.1, R54.2
unnamed: I2C_PU9.1, R55.2
unnamed: I2C_PU9.3, R56.2
unnamed: D10.A, R58.1
unnamed: D10.C, LED9.2
unnamed: ADDR9.3, R59.1
unnamed: ADDR9.1, R60.2
unnamed: I2C_PU10.1, R61.2
unnamed: I2C_PU10.3, R62.2
unnamed: D11.A, R64.1
unnamed: D11.C, LED10.2
unnamed: ADDR10.3, R65.1
unnamed: ADDR10.1, R66.2
unnamed: I2C_PU11.1, R67.2
unnamed: I2C_PU11.3, R68.2
unnamed: D12.A, R70.1
unnamed: D12.C, LED11.2
unnamed: ADDR11.3, R71.1
unnamed: ADDR11.1, R72.2
unnamed: I2C_PU12.1, R73.2
unnamed: I2C_PU12.3, R74.2
unnamed: D13.A, R76.1
unnamed: D13.C, LED12.2
unnamed: ADDR12.3, R77.1
unnamed: ADDR12.1, R78.2
unnamed: I2C_PU13.1, R79.2
unnamed: I2C_PU13.3, R80.2
unnamed: D14.A, R82.1
unnamed: D14.C, LED13.2
unnamed: ADDR13.3, R83.1
unnamed: ADDR13.1, R84.2
unnamed: I2C_PU14.1, R85.2
unnamed: I2C_PU14.3, R86.2
unnamed: D15.A, R88.1
unnamed: D15.C, LED14.2
unnamed: ADDR14.3, R89.1
unnamed: ADDR14.1, R90.2
unnamed: I2C_PU15.1, R91.2
unnamed: I2C_PU15.3, R92.2
unnamed: D16.A, R94.1
unnamed: D16.C, LED15.2
unnamed: ADDR15.3, R95.1
unnamed: ADDR15.1, R96.2
unnamed: I2C_PU16.1, R97.2
unnamed: I2C_PU16.3, R98.2
unnamed: D17.A, R100.1
unnamed: D17.C, LED16.2
unnamed: ADDR16.3, R101.1
unnamed: ADDR16.1, R102.2
unnamed: I2C_PU17.1, R103.2
unnamed: I2C_PU17.3, R104.2
unnamed: D18.A, R106.1
unnamed: D18.C, LED17.2
unnamed: ADDR17.3, R107.1
unnamed: ADDR17.1, R108.2
unnamed: I2C_PU18.1, R109.2
unnamed: I2C_PU18.3, R110.2
unnamed: D19.A, R112.1
unnamed: D19.C, LED18.2
unnamed: ADDR18.3, R113.1
unnamed: ADDR18.1, R114.2
unnamed: I2C_PU19.1, R115.2
unnamed: I2C_PU19.3, R116.2
unnamed: D20.A, R118.1
unnamed: D20.C, LED19.2
unnamed: ADDR19.3, R119.1
unnamed: ADDR19.1, R120.2
unnamed: I2C_PU20.1, R121.2
unnamed: I2C_PU20.3, R122.2
unnamed: D21.A, R124.1
unnamed: D21.C, LED20.2
unnamed: ADDR20.3, R125.1
unnamed: ADDR20.1, R126.2
unnamed: I2C_PU21.1, R127.2
unnamed: I2C_PU21.3, R128.2
unnamed: D22.A, R130.1
unnamed: D22.C, LED21.2
unnamed: ADDR21.3, R131.1
unnamed: ADDR21.1, R132.2
unnamed: I2C_PU22.1, R133.2
unnamed: I2C_PU22.3, R134.2
unnamed: D23.A, R136.1
unnamed: D23.C, LED22.2
unnamed: ADDR22.3, R137.1
unnamed: ADDR22.1, R138.2
unnamed: I2C_PU23.1, R139.2
unnamed: I2C_PU23.3, R140.2
unnamed: D24.A, R142.1
unnamed: D24.C, LED23.2
unnamed: ADDR23.3, R143.1
unnamed: ADDR23.1, R144.2
OCS: JP3.3, U1.P10
OCS1: JP4.3, U2.P10
OCS2: JP6.3, U3.P10
OCS3: JP8.3, U4.P10
OCS4: JP10.3, U5.P10
OCS5: JP12.3, U6.P10
OCS6: JP14.3, U7.P10
OCS7: JP16.3, U8.P10
OCS8: JP18.3, U9.P10
OCS9: JP20.3, U10.P10
OCS10: JP22.3, U11.P10
OCS11: JP24.3, U12.P10
OCS12: JP26.3, U13.P10
OCS13: JP28.3, U14.P10
OCS14: JP30.3, U15.P10
OCS15: JP32.3, U16.P10
OCS16: JP34.3, U17.P10
OCS17: JP36.3, U18.P10
OCS18: JP38.3, U19.P10
OCS19: JP40.3, U20.P10
OCS20: JP42.3, U21.P10
OCS21: JP44.3, U22.P10
OCS22: JP46.3, U23.P10
OCS23: JP48.3, U24.P10
PICO_AUX: JP3.5, SDX.2, U1.P2
PICO_AUX1: JP4.5, SDX1.2, U2.P2
PICO_AUX2: JP6.5, SDX2.2, U3.P2
PICO_AUX3: JP8.5, SDX3.2, U4.P2
PICO_AUX4: JP10.5, SDX4.2, U5.P2
PICO_AUX5: JP12.5, SDX5.2, U6.P2
PICO_AUX6: JP14.5, SDX6.2, U7.P2
PICO_AUX7: JP16.5, SDX7.2, U8.P2
PICO_AUX8: JP18.5, SDX8.2, U9.P2
PICO_AUX9: JP20.5, SDX9.2, U10.P2
PICO_AUX10: JP22.5, SDX10.2, U11.P2
PICO_AUX11: JP24.5, SDX11.2, U12.P2
PICO_AUX12: JP26.5, SDX12.2, U13.P2
PICO_AUX13: JP28.5, SDX13.2, U14.P2
PICO_AUX14: JP30.5, SDX14.2, U15.P2
PICO_AUX15: JP32.5, SDX15.2, U16.P2
PICO_AUX16: JP34.5, SDX16.2, U17.P2
PICO_AUX17: JP36.5, SDX17.2, U18.P2
PICO_AUX18: JP38.5, SDX18.2, U19.P2
PICO_AUX19: JP40.5, SDX19.2, U20.P2
PICO_AUX20: JP42.5, SDX20.2, U21.P2
PICO_AUX21: JP44.5, SDX21.2, U22.P2
PICO_AUX22: JP46.5, SDX22.2, U23.P2
PICO_AUX23: JP48.5, SDX23.2, U24.P2
POCI/SA0: ADDR.2, JP1.1, U1.P1
POCI/SA1: ADDR1.2, JP2.1, U2.P1
POCI/SA2: ADDR2.2, JP5.1, U3.P1
POCI/SA3: ADDR3.2, JP7.1, U4.P1
POCI/SA4: ADDR4.2, JP9.1, U5.P1
POCI/SA5: ADDR5.2, JP11.1, U6.P1
POCI/SA6: ADDR6.2, JP13.1, U7.P1
POCI/SA7: ADDR7.2, JP15.1, U8.P1
POCI/SA8: ADDR8.2, JP17.1, U9.P1
POCI/SA9: ADDR9.2, JP19.1, U10.P1
POCI/SA10: ADDR10.2, JP21.1, U11.P1
POCI/SA11: ADDR11.2, JP23.1, U12.P1
POCI/SA12: ADDR12.2, JP25.1, U13.P1
POCI/SA13: ADDR13.2, JP27.1, U14.P1
POCI/SA14: ADDR14.2, JP29.1, U15.P1
POCI/SA15: ADDR15.2, JP31.1, U16.P1
POCI/SA16: ADDR16.2, JP33.1, U17.P1
POCI/SA17: ADDR17.2, JP35.1, U18.P1
POCI/SA18: ADDR18.2, JP37.1, U19.P1
POCI/SA19: ADDR19.2, JP39.1, U20.P1
POCI/SA20: ADDR20.2, JP41.1, U21.P1
POCI/SA21: ADDR21.2, JP43.1, U22.P1
POCI/SA22: ADDR22.2, JP45.1, U23.P1
POCI/SA23: ADDR23.2, JP47.1, U24.P1
POCI_AUX: JP3.6, U1.P11
POCI_AUX1: JP4.6, U2.P11
POCI_AUX2: JP6.6, U3.P11
POCI_AUX3: JP8.6, U4.P11
POCI_AUX4: JP10.6, U5.P11
POCI_AUX5: JP12.6, U6.P11
POCI_AUX6: JP14.6, U7.P11
POCI_AUX7: JP16.6, U8.P11
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

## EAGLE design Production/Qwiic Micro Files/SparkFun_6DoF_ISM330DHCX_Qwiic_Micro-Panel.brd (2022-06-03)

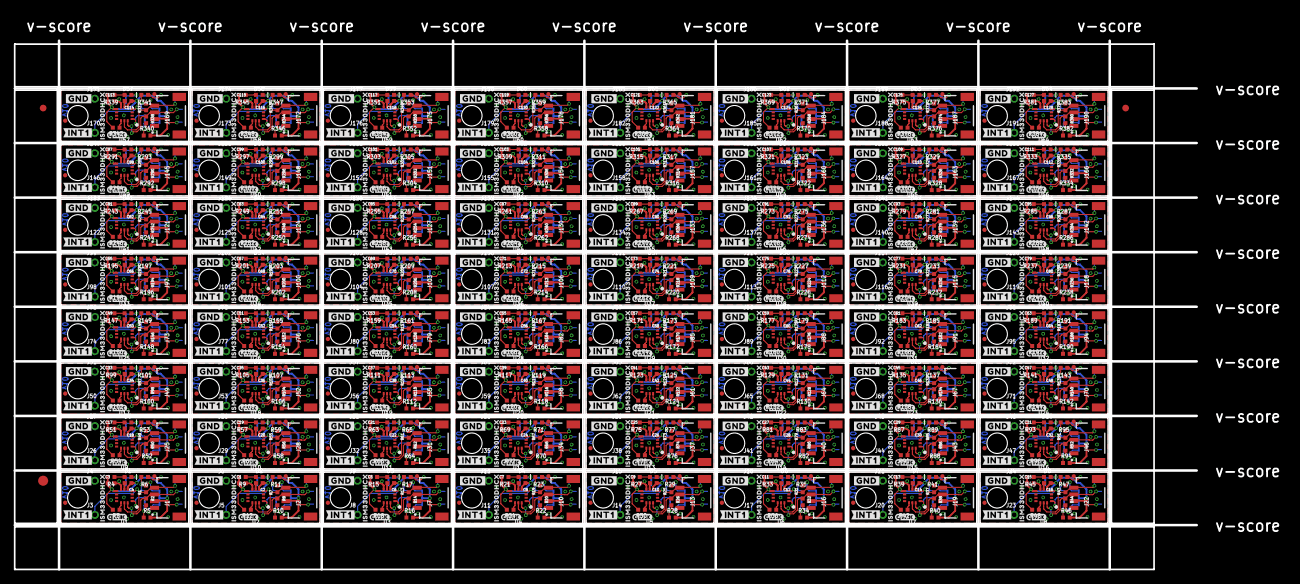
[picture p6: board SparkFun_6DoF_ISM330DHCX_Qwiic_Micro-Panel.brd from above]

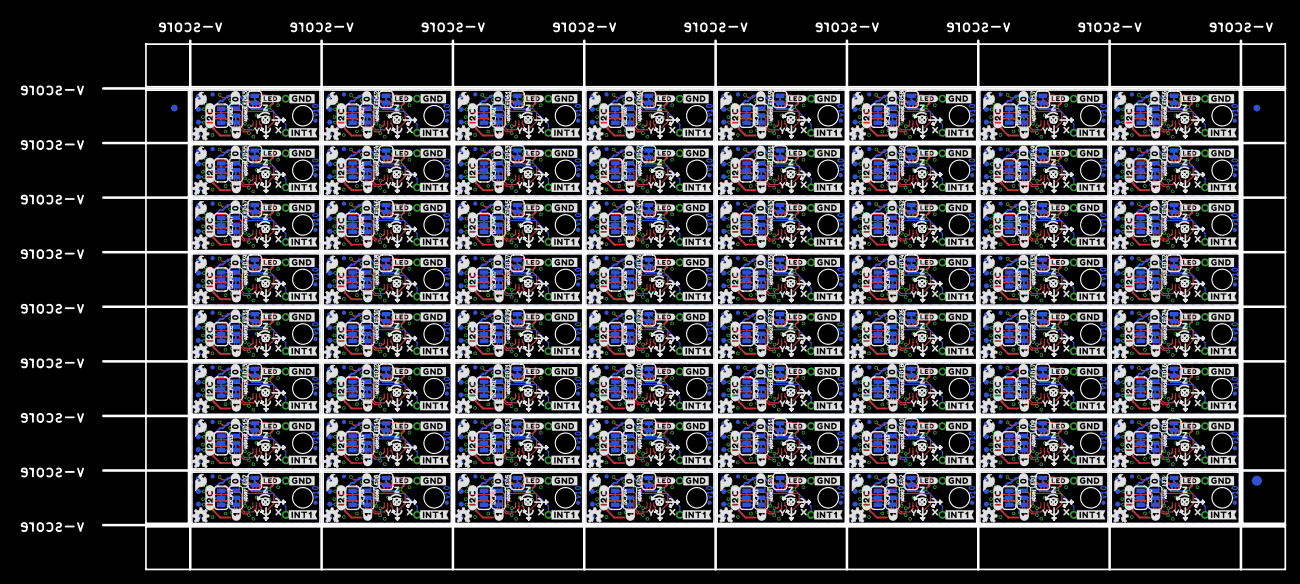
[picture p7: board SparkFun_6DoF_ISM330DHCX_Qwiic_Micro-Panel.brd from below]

Board: 2 copper layers, 176.0 x 78.7 mm, 2630 parts (1283 on the bottom side), 832 nets.

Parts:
ADDR, ADDR1, ADDR2, ADDR3, ADDR4, ADDR5, ADDR6, ADDR7, ADDR8, ADDR9, ADDR10, ADDR11, ADDR12, ADDR13, ADDR14, ADDR15, ADDR16, ADDR17, ADDR18, ADDR19, ADDR20, ADDR21, ADDR22, ADDR23, ADDR24, ADDR25, ADDR26, ADDR27, ADDR28, ADDR29, ADDR30, ADDR31, ADDR32, ADDR33, ADDR34, ADDR35, ADDR36, ADDR37, ADDR38, ADDR39, ADDR40, ADDR41, ADDR42, ADDR43, ADDR44, ADDR45, ADDR46, ADDR47, ADDR48, ADDR49, ADDR50, ADDR51, ADDR52, ADDR53, ADDR54, ADDR55, ADDR56, ADDR57, ADDR58, ADDR59, ADDR60, ADDR61, ADDR62, ADDR63: JUMPER-SMT_3_1-NC_TRACE_SILK; SMT-JUMPER_3_1-NC_TRACE_SILK
C1, C2, C3, C4, C5, C6, C7, C8, C9, C10, C11, C12, C13, C14, C15, C16, C17, C18, C19, C20, C21, C22, C23, C24, C25, C26, C27, C28, C29, C30, C31, C32, C33, C34, C35, C36, C37, C38, C39, C40, C41, C42, C43, C44, C45, C46, C47, C48, C49, C50, C51, C52, C53, C54, C55, C56, C57, C58, C59, C60, C61, C62, C63, C64, C65, C66, C67, C68, C69, C70, C71, C72, C73, C74, C75, C76, C77, C78, C79, C80, C81, C82, C83, C84, C85, C86, C87, C88, C89, C90, C91, C92, C93, C94, C95, C96, C97, C98, C99, C100, C101, C102, C103, C104, C105, C106, C107, C108, C109, C110, C111, C112, C113, C114, C115, C116, C117, C118, C119, C120, C121, C122, C123, C124, C125, C126, C127, C128: 0.1uF; 0402-TIGHT
D1, D2, D3, D4, D5, D6, D7, D8, D9, D10, D11, D12, D13, D14, D15, D16, D17, D18, D19, D20, D21, D22, D23, D24, D25, D26, D27, D28, D29, D30, D31, D32, D33, D34, D35, D36, D37, D38, D39, D40, D41, D42, D43, D44, D45, D46, D47, D48, D49, D50, D51, D52, D53, D54, D55, D56, D57, D58, D59, D60, D61, D62, D63, D64: RED; 0402-TIGHT
E$1, E$2, E$3, E$4: FIDUCIAL-1X2
E$5, E$6: FIDUCIAL-1.5X3
FD1, FD2, FD3, FD4, FD5, FD6, FD7, FD8, FD9, FD10, FD11, FD12, FD13, FD14, FD15, FD16, FD17, FD18, FD19, FD20, FD21, FD22, FD23, FD24, FD25, FD26, FD27, FD28, FD29, FD30, FD31, FD32, FD33, FD34, FD35, FD36, FD37, FD38, FD39, FD40, FD41, FD42, FD43, FD44, FD45, FD46, FD47, FD48, FD49, FD50, FD51, FD52, FD53, FD54, FD55, FD56, FD57, FD58, FD59, FD60, FD61, FD62, FD63, FD64, FD65, FD66, FD67, FD68, FD69, FD70, FD71, FD72, FD73, FD74, FD75, FD76, FD77, FD78, FD79, FD80, FD81, FD82, FD83, FD84, FD85, FD86, FD87, FD88, FD89, FD90, FD91, FD92, FD93, FD94, FD95, FD96, FD97, FD98, FD99, FD100, FD101, FD102, FD103, FD104, FD105, FD106, FD107, FD108, FD109, FD110, FD111, FD112, FD113, FD114, FD115, FD116, FD117, FD118, FD119, FD120, FD121, FD122, FD123, FD124, FD125, FD126, FD127, FD128: FIDUCIALUFIDUCIAL; FIDUCIAL-MICRO
FID1, FID2, FID3, FID4, FID5, FID6, FID7, FID8, FID9, FID10, FID11, FID12, FID13, FID14, FID15, FID16, FID17, FID18, FID19, FID20, FID21, FID22, FID23, FID24, FID25, FID26, FID27, FID28, FID29, FID30, FID31, FID32, FID33, FID34, FID35, FID36, FID37, FID38, FID39, FID40, FID41, FID42, FID43, FID44, FID45, FID46, FID47, FID48, FID49, FID50, FID51, FID52, FID53, FID54, FID55, FID56, FID57, FID58, FID59, FID60, FID61, FID62, FID63, FID64, FID65, FID66, FID67, FID68, FID69, FID70, FID71, FID72, FID73, FID74, FID75, FID76, FID77, FID78, FID79, FID80, FID81, FID82, FID83, FID84, FID85, FID86, FID87, FID88, FID89, FID90, FID91, FID92, FID93, FID94, FID95, FID96, FID97, FID98, FID99, FID100, FID101, FID102, FID103, FID104, FID105, FID106, FID107, FID108, FID109, FID110, FID111, FID112, FID113, FID114, FID115, FID116, FID117, FID118, FID119, FID120, FID121, FID122, FID123, FID124, FID125, FID126, FID127, FID128: FIDUCIALUFIDUCIAL; FIDUCIAL-MICRO
I2C_PU, I2C_PU1, I2C_PU2, I2C_PU3, I2C_PU4, I2C_PU5, I2C_PU6, I2C_PU7, I2C_PU8, I2C_PU9, I2C_PU10, I2C_PU11, I2C_PU12, I2C_PU13, I2C_PU14, I2C_PU15, I2C_PU16, I2C_PU17, I2C_PU18, I2C_PU19, I2C_PU20, I2C_PU21, I2C_PU22, I2C_PU23, I2C_PU24, I2C_PU25, I2C_PU26, I2C_PU27, I2C_PU28, I2C_PU29, I2C_PU30, I2C_PU31, I2C_PU32, I2C_PU33, I2C_PU34, I2C_PU35, I2C_PU36, I2C_PU37, I2C_PU38, I2C_PU39, I2C_PU40, I2C_PU41, I2C_PU42, I2C_PU43, I2C_PU44, I2C_PU45, I2C_PU46, I2C_PU47, I2C_PU48, I2C_PU49, I2C_PU50, I2C_PU51, I2C_PU52, I2C_PU53, I2C_PU54, I2C_PU55, I2C_PU56, I2C_PU57, I2C_PU58, I2C_PU59, I2C_PU60, I2C_PU61, I2C_PU62, I2C_PU63: S_MODE; SMT-JUMPER_3_2-NC_TRACE_SILK
J1, J2, J7, J10, J13, J16, J19, J22, J25, J28, J31, J34, J37, J40, J43, J46, J49, J52, J55, J58, J61, J64, J67, J70, J73, J76, J79, J82, J85, J88, J91, J94, J97, J100, J103, J106, J109, J112, J115, J118, J121, J124, J127, J130, J133, J136, J139, J142, J145, J148, J151, J154, J157, J160, J163, J166, J169, J172, J175, J178, J181, J184, J187, J190: Qwiic Right Angle; JST04_1MM_RA
J3, J4, J5, J6, J8, J9, J11, J12, J14, J15, J17, J18, J20, J21, J23, J24, J26, J27, J29, J30, J32, J33, J35, J36, J38, J39, J41, J42, J44, J45, J47, J48, J50, J51, J53, J54, J56, J57, J59, J60, J62, J63, J65, J66, J68, J69, J71, J72, J74, J75, J77, J78, J80, J81, J83, J84, J86, J87, J89, J90, J92, J93, J95, J96, J98, J99, J101, J102, J104, J105, J107, J108, J110, J111, J113, J114, J116, J117, J119, J120, J122, J123, J125, J126, J128, J129, J131, J132, J134, J135, J137, J138, J140, J141, J143, J144, J146, J147, J149, J150, J152, J153, J155, J156, J158, J159, J161, J162, J164, J165, J167, J168, J170, J171, J173, J174, J176, J177, J179, J180, J182, J183, J185, J186, J188, J189, J191, J192: 1X01_1MM_NO_SILK
LED, LED1, LED2, LED3, LED4, LED5, LED6, LED7, LED8, LED9, LED10, LED11, LED12, LED13, LED14, LED15, LED16, LED17, LED18, LED19, LED20, LED21, LED22, LED23, LED24, LED25, LED26, LED27, LED28, LED29, LED30, LED31, LED32, LED33, LED34, LED35, LED36, LED37, LED38, LED39, LED40, LED41, LED42, LED43, LED44, LED45, LED46, LED47, LED48, LED49, LED50, LED51, LED52, LED53, LED54, LED55, LED56, LED57, LED58, LED59, LED60, LED61, LED62, LED63: JUMPER-SMT_2_NC_TRACE_SILK; SMT-JUMPER_2_NC_TRACE_SILK
LOGO1, LOGO5, LOGO8, LOGO11, LOGO14, LOGO17, LOGO20, LOGO23, LOGO26, LOGO29, LOGO32, LOGO35, LOGO38, LOGO41, LOGO44, LOGO47, LOGO50, LOGO53, LOGO56, LOGO59, LOGO62, LOGO65, LOGO68, LOGO71, LOGO74, LOGO77, LOGO80, LOGO83, LOGO86, LOGO89, LOGO92, LOGO95, LOGO98, LOGO101, LOGO104, LOGO107, LOGO110, LOGO113, LOGO116, LOGO119, LOGO122, LOGO125, LOGO128, LOGO131, LOGO134, LOGO137, LOGO140, LOGO143, LOGO146, LOGO149, LOGO152, LOGO155, LOGO158, LOGO161, LOGO164, LOGO167, LOGO170, LOGO173, LOGO176, LOGO179, LOGO182, LOGO185, LOGO188, LOGO191: QWIIC_LOGO_3MM; QWIIC_3MM
LOGO2, LOGO4, LOGO7, LOGO10, LOGO13, LOGO16, LOGO19, LOGO22, LOGO25, LOGO28, LOGO31, LOGO34, LOGO37, LOGO40, LOGO43, LOGO46, LOGO49, LOGO52, LOGO55, LOGO58, LOGO61, LOGO64, LOGO67, LOGO70, LOGO73, LOGO76, LOGO79, LOGO82, LOGO85, LOGO88, LOGO91, LOGO94, LOGO97, LOGO100, LOGO103, LOGO106, LOGO109, LOGO112, LOGO115, LOGO118, LOGO121, LOGO124, LOGO127, LOGO130, LOGO133, LOGO136, LOGO139, LOGO142, LOGO145, LOGO148, LOGO151, LOGO154, LOGO157, LOGO160, LOGO163, LOGO166, LOGO169, LOGO172, LOGO175, LOGO178, LOGO181, LOGO184, LOGO187, LOGO190: OSHW-LOGOMINI; OSHW-LOGO-MINI
LOGO3, LOGO6, LOGO9, LOGO12, LOGO15, LOGO18, LOGO21, LOGO24, LOGO27, LOGO30, LOGO33, LOGO36, LOGO39, LOGO42, LOGO45, LOGO48, LOGO51, LOGO54, LOGO57, LOGO60, LOGO63, LOGO66, LOGO69, LOGO72, LOGO75, LOGO78, LOGO81, LOGO84, LOGO87, LOGO90, LOGO93, LOGO96, LOGO99, LOGO102, LOGO105, LOGO108, LOGO111, LOGO114, LOGO117, LOGO120, LOGO123, LOGO126, LOGO129, LOGO132, LOGO135, LOGO138, LOGO141, LOGO144, LOGO147, LOGO150, LOGO153, LOGO156, LOGO159, LOGO162, LOGO165, LOGO168, LOGO171, LOGO174, LOGO177, LOGO180, LOGO183, LOGO186, LOGO189, LOGO192: SFE_LOGO_NAME_FLAMEBLANK; BLANK
R1, R2, R7, R8, R13, R14, R19, R20, R25, R26, R31, R32, R37, R38, R43, R44, R49, R50, R55, R56, R61, R62, R67, R68, R73, R74, R79, R80, R85, R86, R91, R92, R97, R98, R103, R104, R109, R110, R115, R116, R121, R122, R127, R128, R133, R134, R139, R140, R145, R146, R151, R152, R157, R158, R163, R164, R169, R170, R175, R176, R181, R182, R187, R188, R193, R194, R199, R200, R205, R206, R211, R212, R217, R218, R223, R224, R229, R230, R235, R236, R241, R242, R247, R248, R253, R254, R259, R260, R265, R266, R271, R272, R277, R278, R283, R284, R289, R290, R295, R296, R301, R302, R307, R308, R313, R314, R319, R320, R325, R326, R331, R332, R337, R338, R343, R344, R349, R350, R355, R356, R361, R362, R367, R368, R373, R374, R379, R380: 2.2k; 0402-TIGHT
R3, R5, R6, R10, R11, R12, R16, R17, R18, R22, R23, R24, R28, R29, R30, R34, R35, R36, R40, R41, R42, R46, R47, R48, R52, R53, R54, R58, R59, R60, R64, R65, R66, R70, R71, R72, R76, R77, R78, R82, R83, R84, R88, R89, R90, R94, R95, R96, R100, R101, R102, R106, R107, R108, R112, R113, R114, R118, R119, R120, R124, R125, R126, R130, R131, R132, R136, R137, R138, R142, R143, R144, R148, R149, R150, R154, R155, R156, R160, R161, R162, R166, R167, R168, R172, R173, R174, R178, R179, R180, R184, R185, R186, R190, R191, R192, R196, R197, R198, R202, R203, R204, R208, R209, R210, R214, R215, R216, R220, R221, R222, R226, R227, R228, R232, R233, R234, R238, R239, R240, R244, R245, R246, R250, R251, R252, R256, R257, R258, R262, R263, R264, R268, R269, R270, R274, R275, R276, R280, R281, R282, R286, R287, R288, R292, R293, R294, R298, R299, R300, R304, R305, R306, R310, R311, R312, R316, R317, R318, R322, R323, R324, R328, R329, R330, R334, R335, R336, R340, R341, R342, R346, R347, R348, R352, R353, R354, R358, R359, R360, R364, R365, R366, R370, R371, R372, R376, R377, R378, R382, R383, R384: 10k; 0402-TIGHT
R4, R9, R15, R21, R27, R33, R39, R45, R51, R57, R63, R69, R75, R81, R87, R93, R99, R105, R111, R117, R123, R129, R135, R141, R147, R153, R159, R165, R171, R177, R183, R189, R195, R201, R207, R213, R219, R225, R231, R237, R243, R249, R255, R261, R267, R273, R279, R285, R291, R297, R303, R309, R315, R321, R327, R333, R339, R345, R351, R357, R363, R369, R375, R381: 1k; 0402-TIGHT
STANDOFF1, STANDOFF2, STANDOFF3, STANDOFF4, STANDOFF5, STANDOFF6, STANDOFF7, STANDOFF8, STANDOFF9, STANDOFF10, STANDOFF11, STANDOFF12, STANDOFF13, STANDOFF14, STANDOFF15, STANDOFF16, STANDOFF17, STANDOFF18, STANDOFF19, STANDOFF20, STANDOFF21, STANDOFF22, STANDOFF23, STANDOFF24, STANDOFF25, STANDOFF26, STANDOFF27, STANDOFF28, STANDOFF29, STANDOFF30, STANDOFF31, STANDOFF32, STANDOFF33, STANDOFF34, STANDOFF35, STANDOFF36, STANDOFF37, STANDOFF38, STANDOFF39, STANDOFF40, STANDOFF41, STANDOFF42, STANDOFF43, STANDOFF44, STANDOFF45, STANDOFF46, STANDOFF47, STANDOFF48, STANDOFF49, STANDOFF50, STANDOFF51, STANDOFF52, STANDOFF53, STANDOFF54, STANDOFF55, STANDOFF56, STANDOFF57, STANDOFF58, STANDOFF59, STANDOFF60, STANDOFF61, STANDOFF62, STANDOFF63, STANDOFF64: STAND-OFFTIGHT; STAND-OFF-TIGHT
TP1, TP2, TP3, TP4, TP5, TP6, TP7, TP8, TP9, TP10, TP11, TP12, TP13, TP14, TP15, TP16, TP17, TP18, TP19, TP20, TP21, TP22, TP23, TP24, TP25, TP26, TP27, TP28, TP29, TP30, TP31, TP32, TP33, TP34, TP35, TP36, TP37, TP38, TP39, TP40, TP41, TP42, TP43, TP44, TP45, TP46, TP47, TP48, TP49, TP50, TP51, TP52, TP53, TP54, TP55, TP56, TP57, TP58, TP59, TP60, TP61, TP62, TP63, TP64, TP65, TP66, TP67, TP68, TP69, TP70, TP71, TP72, TP73, TP74, TP75, TP76, TP77, TP78, TP79, TP80, TP81, TP82, TP83, TP84, TP85, TP86, TP87, TP88, TP89, TP90, TP91, TP92, TP93, TP94, TP95, TP96, TP97, TP98, TP99, TP100, TP101, TP102, TP103, TP104, TP105, TP106, TP107, TP108, TP109, TP110, TP111, TP112, TP113, TP114, TP115, TP116, TP117, TP118, TP119, TP120, TP121, TP122, TP123, TP124, TP125, TP126, TP127, TP128, TP129, TP130, TP131, TP132, TP133, TP134, TP135, TP136, TP137, TP138, TP139, TP140, TP141, TP142, TP143, TP144, TP145, TP146, TP147, TP148, TP149, TP150, TP151, TP152, TP153, TP154, TP155, TP156, TP157, TP158, TP159, TP160, TP161, TP162, TP163, TP164, TP165, TP166, TP167, TP168, TP169, TP170, TP171, TP172, TP173, TP174, TP175, TP176, TP177, TP178, TP179, TP180, TP181, TP182, TP183, TP184, TP185, TP186, TP187, TP188, TP189, TP190, TP191, TP192, TP193, TP194, TP195, TP196, TP197, TP198, TP199, TP200, TP201, TP202, TP203, TP204, TP205, TP206, TP207, TP208, TP209, TP210, TP211, TP212, TP213, TP214, TP215, TP216, TP217, TP218, TP219, TP220, TP221, TP222, TP223, TP224, TP225, TP226, TP227, TP228, TP229, TP230, TP231, TP232, TP233, TP234, TP235, TP236, TP237, TP238, TP239, TP240, TP241, TP242, TP243, TP244, TP245, TP246, TP247, TP248, TP249, TP250, TP251, TP252, TP253, TP254, TP255, TP256: TEST-POINT3; PAD.03X.03
U1, U2, U3, U4, U5, U6, U7, U8, U9, U10, U11, U12, U13, U14, U15, U16, U17, U18, U19, U20, U21, U22, U23, U24, U25, U26, U27, U28, U29, U30, U31, U32, U33, U34, U35, U36, U37, U38, U39, U40, U41, U42, U43, U44, U45, U46, U47, U48, U49, U50, U51, U52, U53, U54, U55, U56, U57, U58, U59, U60, U61, U62, U63, U64: ISM330DHCX; LGA-14L
U$1, U$19, U$33, U$46, U$59, U$72, U$85, U$98, U$111, U$124, U$137, U$150, U$163, U$176, U$189, U$202, U$215, U$228, U$241, U$254, U$267, U$280, U$293, U$306, U$319, U$332, U$345, U$358, U$371, U$384, U$397, U$410, U$423, U$436, U$449, U$462, U$475, U$488, U$501, U$514, U$527, U$540, U$553, U$566, U$579, U$592, U$605, U$618, U$631, U$644, U$657, U$670, U$683, U$696, U$709, U$722, U$735, U$748, U$761, U$774, U$787, U$800, U$813, U$826: #0#4
U$2, U$20, U$34, U$47, U$60, U$73, U$86, U$99, U$112, U$125, U$138, U$151, U$164, U$177, U$190, U$203, U$216, U$229, U$242, U$255, U$268, U$281, U$294, U$307, U$320, U$333, U$346, U$359, U$372, U$385, U$398, U$411, U$424, U$437, U$450, U$463, U$476, U$489, U$502, U$515, U$528, U$541, U$554, U$567, U$580, U$593, U$606, U$619, U$632, U$645, U$658, U$671, U$684, U$697, U$710, U$723, U$736, U$749, U$762, U$775, U$788, U$801, U$814, U$827: #1#4
U$3, U$17, U$31, U$44, U$57, U$70, U$83, U$96, U$109, U$122, U$135, U$148, U$161, U$174, U$187, U$200, U$213, U$226, U$239, U$252, U$265, U$278, U$291, U$304, U$317, U$330, U$343, U$356, U$369, U$382, U$395, U$408, U$421, U$434, U$447, U$460, U$473, U$486, U$499, U$512, U$525, U$538, U$551, U$564, U$577, U$590, U$603, U$616, U$629, U$642, U$655, U$668, U$681, U$694, U$707, U$720, U$733, U$746, U$759, U$772, U$785, U$798, U$811, U$824: #LED#2121
U$4, U$10, U$22, U$23, U$36, U$37, U$49, U$50, U$62, U$63, U$75, U$76, U$88, U$89, U$101, U$102, U$114, U$115, U$127, U$128, U$140, U$141, U$153, U$154, U$166, U$167, U$179, U$180, U$192, U$193, U$205, U$206, U$218, U$219, U$231, U$232, U$244, U$245, U$257, U$258, U$270, U$271, U$283, U$284, U$296, U$297, U$309, U$310, U$322, U$323, U$335, U$336, U$348, U$349, U$361, U$362, U$374, U$375, U$387, U$388, U$400, U$401, U$413, U$414, U$426, U$427, U$439, U$440, U$452, U$453, U$465, U$466, U$478, U$479, U$491, U$492, U$504, U$505, U$517, U$518, U$530, U$531, U$543, U$544, U$556, U$557, U$569, U$570, U$582, U$583, U$595, U$596, U$608, U$609, U$621, U$622, U$634, U$635, U$647, U$648, U$660, U$661, U$673, U$674, U$686, U$687, U$699, U$700, U$712, U$713, U$725, U$726, U$738, U$739, U$751, U$752, U$764, U$765, U$777, U$778, U$790, U$791, U$803, U$804, U$816, U$817, U$829, U$830: #GND#4
U$5, U$24, U$38, U$51, U$64, U$77, U$90, U$103, U$116, U$129, U$142, U$155, U$168, U$181, U$194, U$207, U$220, U$233, U$246, U$259, U$272, U$285, U$298, U$311, U$324, U$337, U$350, U$363, U$376, U$389, U$402, U$415, U$428, U$441, U$454, U$467, U$480, U$493, U$506, U$519, U$532, U$545, U$558, U$571, U$584, U$597, U$610, U$623, U$636, U$649, U$662, U$675, U$688, U$701, U$714, U$727, U$740, U$753, U$766, U$779, U$792, U$805, U$818, U$831: #INT1#0
U$6, U$18, U$32, U$45, U$58, U$71, U$84, U$97, U$110, U$123, U$136, U$149, U$162, U$175, U$188, U$201, U$214, U$227, U$240, U$253, U$266, U$279, U$292, U$305, U$318, U$331, U$344, U$357, U$370, U$383, U$396, U$409, U$422, U$435, U$448, U$461, U$474, U$487, U$500, U$513, U$526, U$539, U$552, U$565, U$578, U$591, U$604, U$617, U$630, U$643, U$656, U$669, U$682, U$695, U$708, U$721, U$734, U$747, U$760, U$773, U$786, U$799, U$812, U$825: ISM330DHCX2120
U$7, U$14, U$27, U$41, U$54, U$67, U$80, U$93, U$106, U$119, U$132, U$145, U$158, U$171, U$184, U$197, U$210, U$223, U$236, U$249, U$262, U$275, U$288, U$301, U$314, U$327, U$340, U$353, U$366, U$379, U$392, U$405, U$418, U$431, U$444, U$457, U$470, U$483, U$496, U$509, U$522, U$535, U$548, U$561, U$574, U$587, U$600, U$613, U$626, U$639, U$652, U$665, U$678, U$691, U$704, U$717, U$730, U$743, U$756, U$769, U$782, U$795, U$808, U$821: X2114
U$8, U$15, U$28, U$42, U$55, U$68, U$81, U$94, U$107, U$120, U$133, U$146, U$159, U$172, U$185, U$198, U$211, U$224, U$237, U$250, U$263, U$276, U$289, U$302, U$315, U$328, U$341, U$354, U$367, U$380, U$393, U$406, U$419, U$432, U$445, U$458, U$471, U$484, U$497, U$510, U$523, U$536, U$549, U$562, U$575, U$588, U$601, U$614, U$627, U$640, U$653, U$666, U$679, U$692, U$705, U$718, U$731, U$744, U$757, U$770, U$783, U$796, U$809, U$822: Y2115
U$9, U$16, U$30, U$43, U$56, U$69, U$82, U$95, U$108, U$121, U$134, U$147, U$160, U$173, U$186, U$199, U$212, U$225, U$238, U$251, U$264, U$277, U$290, U$303, U$316, U$329, U$342, U$355, U$368, U$381, U$394, U$407, U$420, U$433, U$446, U$459, U$472, U$485, U$498, U$511, U$524, U$537, U$550, U$563, U$576, U$589, U$602, U$615, U$628, U$641, U$654, U$667, U$680, U$693, U$706, U$719, U$732, U$745, U$758, U$771, U$784, U$797, U$810, U$823: Z2116
U$11, U$25, U$39, U$52, U$65, U$78, U$91, U$104, U$117, U$130, U$143, U$156, U$169, U$182, U$195, U$208, U$221, U$234, U$247, U$260, U$273, U$286, U$299, U$312, U$325, U$338, U$351, U$364, U$377, U$390, U$403, U$416, U$429, U$442, U$455, U$468, U$481, U$494, U$507, U$520, U$533, U$546, U$559, U$572, U$585, U$598, U$611, U$624, U$637, U$650, U$663, U$676, U$689, U$702, U$715, U$728, U$741, U$754, U$767, U$780, U$793, U$806, U$819, U$832: #INT1#2
U$12, U$21, U$35, U$48, U$61, U$74, U$87, U$100, U$113, U$126, U$139, U$152, U$165, U$178, U$191, U$204, U$217, U$230, U$243, U$256, U$269, U$282, U$295, U$308, U$321, U$334, U$347, U$360, U$373, U$386, U$399, U$412, U$425, U$438, U$451, U$464, U$477, U$490, U$503, U$516, U$529, U$542, U$555, U$568, U$581, U$594, U$607, U$620, U$633, U$646, U$659, U$672, U$685, U$698, U$711, U$724, U$737, U$750, U$763, U$776, U$789, U$802, U$815, U$828: #I2C#4
U$13, U$26, U$29, U$40, U$53, U$66, U$79, U$92, U$105, U$118, U$131, U$144, U$157, U$170, U$183, U$196, U$209, U$222, U$235, U$248, U$261, U$274, U$287, U$300, U$313, U$326, U$339, U$352, U$365, U$378, U$391, U$404, U$417, U$430, U$443, U$456, U$469, U$482, U$495, U$508, U$521, U$534, U$547, U$560, U$573, U$586, U$599, U$612, U$625, U$638, U$651, U$664, U$677, U$690, U$703, U$716, U$729, U$742, U$755, U$768, U$781, U$794, U$807, U$820: SFE_LOGO_FLAME_.1

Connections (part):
3.3V: C3.1, C4.1, I2C_PU.2, J1.2, R3.2, R4.2, R5.2, TP3.1, U1.P5, U1.P8
3.3V1: C1.1, C2.1, I2C_PU1.2, J2.2, R9.2, R10.2, R12.2, TP7.1, U2.P5, U2.P8
3.3V2: C5.1, C6.1, I2C_PU2.2, J7.2, R15.2, R16.2, R18.2, TP11.1, U3.P5, U3.P8
3.3V3: C7.1, C8.1, I2C_PU3.2, J10.2, R21.2, R22.2, R24.2, TP15.1, U4.P5, U4.P8
3.3V4: C9.1, C10.1, I2C_PU4.2, J13.2, R27.2, R28.2, R30.2, TP19.1, U5.P5, U5.P8
3.3V5: C11.1, C12.1, I2C_PU5.2, J16.2, R33.2, R34.2, R36.2, TP23.1, U6.P5, U6.P8
3.3V6: C13.1, C14.1, I2C_PU6.2, J19.2, R39.2, R40.2, R42.2, TP27.1, U7.P5, U7.P8
3.3V7: C15.1, C16.1, I2C_PU7.2, J22.2, R45.2, R46.2, R48.2, TP31.1, U8.P5, U8.P8
3.3V8: C17.1, C18.1, I2C_PU8.2, J25.2, R51.2, R52.2, R54.2, TP35.1, U9.P5, U9.P8
3.3V9: C19.1, C20.1, I2C_PU9.2, J28.2, R57.2, R58.2, R60.2, TP39.1, U10.P5, U10.P8
3.3V10: C21.1, C22.1, I2C_PU10.2, J31.2, R63.2, R64.2, R66.2, TP43.1, U11.P5, U11.P8
3.3V11: C23.1, C24.1, I2C_PU11.2, J34.2, R69.2, R70.2, R72.2, TP47.1, U12.P5, U12.P8
3.3V12: C25.1, C26.1, I2C_PU12.2, J37.2, R75.2, R76.2, R78.2, TP51.1, U13.P5, U13.P8
3.3V13: C27.1, C28.1, I2C_PU13.2, J40.2, R81.2, R82.2, R84.2, TP55.1, U14.P5, U14.P8
3.3V14: C29.1, C30.1, I2C_PU14.2, J43.2, R87.2, R88.2, R90.2, TP59.1, U15.P5, U15.P8
3.3V15: C31.1, C32.1, I2C_PU15.2, J46.2, R93.2, R94.2, R96.2, TP63.1, U16.P5, U16.P8
3.3V16: C33.1, C34.1, I2C_PU16.2, J49.2, R99.2, R100.2, R102.2, TP67.1, U17.P5, U17.P8
3.3V17: C35.1, C36.1, I2C_PU17.2, J52.2, R105.2, R106.2, R108.2, TP71.1, U18.P5, U18.P8
3.3V18: C37.1, C38.1, I2C_PU18.2, J55.2, R111.2, R112.2, R114.2, TP75.1, U19.P5, U19.P8
3.3V19: C39.1, C40.1, I2C_PU19.2, J58.2, R117.2, R118.2, R120.2, TP79.1, U20.P5, U20.P8
3.3V20: C41.1, C42.1, I2C_PU20.2, J61.2, R123.2, R124.2, R126.2, TP83.1, U21.P5, U21.P8
3.3V21: C43.1, C44.1, I2C_PU21.2, J64.2, R129.2, R130.2, R132.2, TP87.1, U22.P5, U22.P8
3.3V22: C45.1, C46.1, I2C_PU22.2, J67.2, R135.2, R136.2, R138.2, TP91.1, U23.P5, U23.P8
3.3V23: C47.1, C48.1, I2C_PU23.2, J70.2, R141.2, R142.2, R144.2, TP95.1, U24.P5, U24.P8
3.3V24: C49.1, C50.1, I2C_PU24.2, J73.2, R147.2, R148.2, R150.2, TP99.1, U25.P5, U25.P8
3.3V25: C51.1, C52.1, I2C_PU25.2, J76.2, R153.2, R154.2, R156.2, TP103.1, U26.P5, U26.P8
3.3V26: C53.1, C54.1, I2C_PU26.2, J79.2, R159.2, R160.2, R162.2, TP107.1, U27.P5, U27.P8
3.3V27: C55.1, C56.1, I2C_PU27.2, J82.2, R165.2, R166.2, R168.2, TP111.1, U28.P5, U28.P8
3.3V28: C57.1, C58.1, I2C_PU28.2, J85.2, R171.2, R172.2, R174.2, TP115.1, U29.P5, U29.P8
3.3V29: C59.1, C60.1, I2C_PU29.2, J88.2, R177.2, R178.2, R180.2, TP119.1, U30.P5, U30.P8
3.3V30: C61.1, C62.1, I2C_PU30.2, J91.2, R183.2, R184.2, R186.2, TP123.1, U31.P5, U31.P8
3.3V31: C63.1, C64.1, I2C_PU31.2, J94.2, R189.2, R190.2, R192.2, TP127.1, U32.P5, U32.P8
3.3V32: C65.1, C66.1, I2C_PU32.2, J97.2, R195.2, R196.2, R198.2, TP131.1, U33.P5, U33.P8
3.3V33: C67.1, C68.1, I2C_PU33.2, J100.2, R201.2, R202.2, R204.2, TP135.1, U34.P5, U34.P8
3.3V34: C69.1, C70.1, I2C_PU34.2, J103.2, R207.2, R208.2, R210.2, TP139.1, U35.P5, U35.P8
3.3V35: C71.1, C72.1, I2C_PU35.2, J106.2, R213.2, R214.2, R216.2, TP143.1, U36.P5, U36.P8
3.3V36: C73.1, C74.1, I2C_PU36.2, J109.2, R219.2, R220.2, R222.2, TP147.1, U37.P5, U37.P8
3.3V37: C75.1, C76.1, I2C_PU37.2, J112.2, R225.2, R226.2, R228.2, TP151.1, U38.P5, U38.P8
3.3V38: C77.1, C78.1, I2C_PU38.2, J115.2, R231.2, R232.2, R234.2, TP155.1, U39.P5, U39.P8
3.3V39: C79.1, C80.1, I2C_PU39.2, J118.2, R237.2, R238.2, R240.2, TP159.1, U40.P5, U40.P8
3.3V40: C81.1, C82.1, I2C_PU40.2, J121.2, R243.2, R244.2, R246.2, TP163.1, U41.P5, U41.P8
3.3V41: C83.1, C84.1, I2C_PU41.2, J124.2, R249.2, R250.2, R252.2, TP167.1, U42.P5, U42.P8
3.3V42: C85.1, C86.1, I2C_PU42.2, J127.2, R255.2, R256.2, R258.2, TP171.1, U43.P5, U43.P8
3.3V43: C87.1, C88.1, I2C_PU43.2, J130.2, R261.2, R262.2, R264.2, TP175.1, U44.P5, U44.P8
3.3V44: C89.1, C90.1, I2C_PU44.2, J133.2, R267.2, R268.2, R270.2, TP179.1, U45.P5, U45.P8
3.3V45: C91.1, C92.1, I2C_PU45.2, J136.2, R273.2, R274.2, R276.2, TP183.1, U46.P5, U46.P8
3.3V46: C93.1, C94.1, I2C_PU46.2, J139.2, R279.2, R280.2, R282.2, TP187.1, U47.P5, U47.P8
3.3V47: C95.1, C96.1, I2C_PU47.2, J142.2, R285.2, R286.2, R288.2, TP191.1, U48.P5, U48.P8
3.3V48: C97.1, C98.1, I2C_PU48.2, J145.2, R291.2, R292.2, R294.2, TP195.1, U49.P5, U49.P8
3.3V49: C99.1, C100.1, I2C_PU49.2, J148.2, R297.2, R298.2, R300.2, TP199.1, U50.P5, U50.P8
3.3V50: C101.1, C102.1, I2C_PU50.2, J151.2, R303.2, R304.2, R306.2, TP203.1, U51.P5, U51.P8
3.3V51: C103.1, C104.1, I2C_PU51.2, J154.2, R309.2, R310.2, R312.2, TP207.1, U52.P5, U52.P8
3.3V52: C105.1, C106.1, I2C_PU52.2, J157.2, R315.2, R316.2, R318.2, TP211.1, U53.P5, U53.P8
3.3V53: C107.1, C108.1, I2C_PU53.2, J160.2, R321.2, R322.2, R324.2, TP215.1, U54.P5, U54.P8
3.3V54: C109.1, C110.1, I2C_PU54.2, J163.2, R327.2, R328.2, R330.2, TP219.1, U55.P5, U55.P8
3.3V55: C111.1, C112.1, I2C_PU55.2, J166.2, R333.2, R334.2, R336.2, TP223.1, U56.P5, U56.P8
3.3V56: C113.1, C114.1, I2C_PU56.2, J169.2, R339.2, R340.2, R342.2, TP227.1, U57.P5, U57.P8
3.3V57: C115.1, C116.1, I2C_PU57.2, J172.2, R345.2, R346.2, R348.2, TP231.1, U58.P5, U58.P8
3.3V58: C117.1, C118.1, I2C_PU58.2, J175.2, R351.2, R352.2, R354.2, TP235.1, U59.P5, U59.P8
3.3V59: C119.1, C120.1, I2C_PU59.2, J178.2, R357.2, R358.2, R360.2, TP239.1, U60.P5, U60.P8
3.3V60: C121.1, C122.1, I2C_PU60.2, J181.2, R363.2, R364.2, R366.2, TP243.1, U61.P5, U61.P8
3.3V61: C123.1, C124.1, I2C_PU61.2, J184.2, R369.2, R370.2, R372.2, TP247.1, U62.P5, U62.P8
3.3V62: C125.1, C126.1, I2C_PU62.2, J187.2, R375.2, R376.2, R378.2, TP251.1, U63.P5, U63.P8
3.3V63: C127.1, C128.1, I2C_PU63.2, J190.2, R381.2, R382.2, R384.2, TP255.1, U64.P5, U64.P8
GND: C3.2, C4.2, J1.1, J4.1, LED.1, R6.1, TP4.1, U1.P6, U1.P7
GND1: C1.2, C2.2, J2.1, J6.1, LED1.1, R11.1, TP8.1, U2.P6, U2.P7
GND2: C5.2, C6.2, J7.1, J9.1, LED2.1, R17.1, TP12.1, U3.P6, U3.P7
GND3: C7.2, C8.2, J10.1, J12.1, LED3.1, R23.1, TP16.1, U4.P6, U4.P7
GND4: C9.2, C10.2, J13.1, J15.1, LED4.1, R29.1, TP20.1, U5.P6, U5.P7
GND5: C11.2, C12.2, J16.1, J18.1, LED5.1, R35.1, TP24.1, U6.P6, U6.P7
GND6: C13.2, C14.2, J19.1, J21.1, LED6.1, R41.1, TP28.1, U7.P6, U7.P7
GND7: C15.2, C16.2, J22.1, J24.1, LED7.1, R47.1, TP32.1, U8.P6, U8.P7
GND8: C17.2, C18.2, J25.1, J27.1, LED8.1, R53.1, TP36.1, U9.P6, U9.P7
GND9: C19.2, C20.2, J28.1, J30.1, LED9.1, R59.1, TP40.1, U10.P6, U10.P7
GND10: C21.2, C22.2, J31.1, J33.1, LED10.1, R65.1, TP44.1, U11.P6, U11.P7
GND11: C23.2, C24.2, J34.1, J36.1, LED11.1, R71.1, TP48.1, U12.P6, U12.P7
GND12: C25.2, C26.2, J37.1, J39.1, LED12.1, R77.1, TP52.1, U13.P6, U13.P7
GND13: C27.2, C28.2, J40.1, J42.1, LED13.1, R83.1, TP56.1, U14.P6, U14.P7
GND14: C29.2, C30.2, J43.1, J45.1, LED14.1, R89.1, TP60.1, U15.P6, U15.P7
GND15: C31.2, C32.2, J46.1, J48.1, LED15.1, R95.1, TP64.1, U16.P6, U16.P7
GND16: C33.2, C34.2, J49.1, J51.1, LED16.1, R101.1, TP68.1, U17.P6, U17.P7
GND17: C35.2, C36.2, J52.1, J54.1, LED17.1, R107.1, TP72.1, U18.P6, U18.P7
GND18: C37.2, C38.2, J55.1, J57.1, LED18.1, R113.1, TP76.1, U19.P6, U19.P7
GND19: C39.2, C40.2, J58.1, J60.1, LED19.1, R119.1, TP80.1, U20.P6, U20.P7
GND20: C41.2, C42.2, J61.1, J63.1, LED20.1, R125.1, TP84.1, U21.P6, U21.P7
GND21: C43.2, C44.2, J64.1, J66.1, LED21.1, R131.1, TP88.1, U22.P6, U22.P7
GND22: C45.2, C46.2, J67.1, J69.1, LED22.1, R137.1, TP92.1, U23.P6, U23.P7
GND23: C47.2, C48.2, J70.1, J72.1, LED23.1, R143.1, TP96.1, U24.P6, U24.P7
GND24: C49.2, C50.2, J73.1, J75.1, LED24.1, R149.1, TP100.1, U25.P6, U25.P7
GND25: C51.2, C52.2, J76.1, J78.1, LED25.1, R155.1, TP104.1, U26.P6, U26.P7
GND26: C53.2, C54.2, J79.1, J81.1, LED26.1, R161.1, TP108.1, U27.P6, U27.P7
GND27: C55.2, C56.2, J82.1, J84.1, LED27.1, R167.1, TP112.1, U28.P6, U28.P7
GND28: C57.2, C58.2, J85.1, J87.1, LED28.1, R173.1, TP116.1, U29.P6, U29.P7
GND29: C59.2, C60.2, J88.1, J90.1, LED29.1, R179.1, TP120.1, U30.P6, U30.P7
GND30: C61.2, C62.2, J91.1, J93.1, LED30.1, R185.1, TP124.1, U31.P6, U31.P7
GND31: C63.2, C64.2, J94.1, J96.1, LED31.1, R191.1, TP128.1, U32.P6, U32.P7
GND32: C65.2, C66.2, J97.1, J99.1, LED32.1, R197.1, TP132.1, U33.P6, U33.P7
GND33: C67.2, C68.2, J100.1, J102.1, LED33.1, R203.1, TP136.1, U34.P6, U34.P7
GND34: C69.2, C70.2, J103.1, J105.1, LED34.1, R209.1, TP140.1, U35.P6, U35.P7
GND35: C71.2, C72.2, J106.1, J108.1, LED35.1, R215.1, TP144.1, U36.P6, U36.P7
GND36: C73.2, C74.2, J109.1, J111.1, LED36.1, R221.1, TP148.1, U37.P6, U37.P7
GND37: C75.2, C76.2, J112.1, J114.1, LED37.1, R227.1, TP152.1, U38.P6, U38.P7
GND38: C77.2, C78.2, J115.1, J117.1, LED38.1, R233.1, TP156.1, U39.P6, U39.P7
GND39: C79.2, C80.2, J118.1, J120.1, LED39.1, R239.1, TP160.1, U40.P6, U40.P7
GND40: C81.2, C82.2, J121.1, J123.1, LED40.1, R245.1, TP164.1, U41.P6, U41.P7
GND41: C83.2, C84.2, J124.1, J126.1, LED41.1, R251.1, TP168.1, U42.P6, U42.P7
GND42: C85.2, C86.2, J127.1, J129.1, LED42.1, R257.1, TP172.1, U43.P6, U43.P7
GND43: C87.2, C88.2, J130.1, J132.1, LED43.1, R263.1, TP176.1, U44.P6, U44.P7
GND44: C89.2, C90.2, J133.1, J135.1, LED44.1, R269.1, TP180.1, U45.P6, U45.P7
GND45: C91.2, C92.2, J136.1, J138.1, LED45.1, R275.1, TP184.1, U46.P6, U46.P7
GND46: C93.2, C94.2, J139.1, J141.1, LED46.1, R281.1, TP188.1, U47.P6, U47.P7
GND47: C95.2, C96.2, J142.1, J144.1, LED47.1, R287.1, TP192.1, U48.P6, U48.P7
GND48: C97.2, C98.2, J145.1, J147.1, LED48.1, R293.1, TP196.1, U49.P6, U49.P7
GND49: C99.2, C100.2, J148.1, J150.1, LED49.1, R299.1, TP200.1, U50.P6, U50.P7
GND50: C101.2, C102.2, J151.1, J153.1, LED50.1, R305.1, TP204.1, U51.P6, U51.P7
GND51: C103.2, C104.2, J154.1, J156.1, LED51.1, R311.1, TP208.1, U52.P6, U52.P7
GND52: C105.2, C106.2, J157.1, J159.1, LED52.1, R317.1, TP212.1, U53.P6, U53.P7
GND53: C107.2, C108.2, J160.1, J162.1, LED53.1, R323.1, TP216.1, U54.P6, U54.P7
GND54: C109.2, C110.2, J163.1, J165.1, LED54.1, R329.1, TP220.1, U55.P6, U55.P7
GND55: C111.2, C112.2, J166.1, J168.1, LED55.1, R335.1, TP224.1, U56.P6, U56.P7
GND56: C113.2, C114.2, J169.1, J171.1, LED56.1, R341.1, TP228.1, U57.P6, U57.P7
GND57: C115.2, C116.2, J172.1, J174.1, LED57.1, R347.1, TP232.1, U58.P6, U58.P7
GND58: C117.2, C118.2, J175.1, J177.1, LED58.1, R353.1, TP236.1, U59.P6, U59.P7
GND59: C119.2, C120.2, J178.1, J180.1, LED59.1, R359.1, TP240.1, U60.P6, U60.P7
GND60: C121.2, C122.2, J181.1, J183.1, LED60.1, R365.1, TP244.1, U61.P6, U61.P7
GND61: C123.2, C124.2, J184.1, J186.1, LED61.1, R371.1, TP248.1, U62.P6, U62.P7
GND62: C125.2, C126.2, J187.1, J189.1, LED62.1, R377.1, TP252.1, U63.P6, U63.P7
GND63: C127.2, C128.2, J190.1, J192.1, LED63.1, R383.1, TP256.1, U64.P6, U64.P7
INT1: J3.1, U1.P4
INT2: J5.1, U2.P4
INT3: J8.1, U3.P4
INT4: J11.1, U4.P4
INT5: J14.1, U5.P4
INT6: J17.1, U6.P4
INT7: J20.1, U7.P4
INT8: J23.1, U8.P4
INT9: J26.1, U9.P4
INT10: J29.1, U10.P4
INT11: J32.1, U11.P4
INT12: J35.1, U12.P4
INT13: J38.1, U13.P4
INT14: J41.1, U14.P4
INT15: J44.1, U15.P4
INT16: J47.1, U16.P4
INT17: J50.1, U17.P4
INT18: J53.1, U18.P4
INT19: J56.1, U19.P4
INT20: J59.1, U20.P4
INT21: J62.1, U21.P4
INT22: J65.1, U22.P4
INT23: J68.1, U23.P4
INT24: J71.1, U24.P4
INT25: J74.1, U25.P4
INT26: J77.1, U26.P4
INT27: J80.1, U27.P4
INT28: J83.1, U28.P4
INT29: J86.1, U29.P4
INT30: J89.1, U30.P4
INT31: J92.1, U31.P4
INT32: J95.1, U32.P4
INT33: J98.1, U33.P4
INT34: J101.1, U34.P4
INT35: J104.1, U35.P4
INT36: J107.1, U36.P4
INT37: J110.1, U37.P4
INT38: J113.1, U38.P4
INT39: J116.1, U39.P4
INT40: J119.1, U40.P4
INT41: J122.1, U41.P4
INT42: J125.1, U42.P4
INT43: J128.1, U43.P4
INT44: J131.1, U44.P4
INT45: J134.1, U45.P4
INT46: J137.1, U46.P4
INT47: J140.1, U47.P4
INT48: J143.1, U48.P4
INT49: J146.1, U49.P4
INT50: J149.1, U50.P4
INT51: J152.1, U51.P4
INT52: J155.1, U52.P4
INT53: J158.1, U53.P4
INT54: J161.1, U54.P4
INT55: J164.1, U55.P4
INT56: J167.1, U56.P4
INT57: J170.1, U57.P4
INT58: J173.1, U58.P4
INT59: J176.1, U59.P4
INT60: J179.1, U60.P4
INT61: J182.1, U61.P4
INT62: J185.1, U62.P4
INT63: J188.1, U63.P4
INT64: J191.1, U64.P4
unnamed: ADDR.3, R5.1
unnamed: D1.A, R4.1
unnamed: D1.C, LED.2
unnamed: R3.1, U1.P12
unnamed: I2C_PU.1, R1.2
unnamed: I2C_PU.3, R2.2
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

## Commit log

2022-02-28 Adds documentation, copies over other 6DoF For basic shell of a design
    [SparkFun_6DoF_ISM330DHCX.brd, SparkFun_6DoF_ISM330DHCX.sch]
2022-03-01 Adds ISM330DHCX part
    [SparkFun_6DoF_ISM330DHCX.sch]
2022-03-01 Fixes IC name
    [SparkFun_6DoF_ISM330DHCX.brd, SparkFun_6DoF_ISM330DHCX.sch]
2022-04-01 Updates notes in schematic (schematic done)
    * Adds 10k to ground to address selection just in case someone bridges the entire three way jumper
    [SparkFun_6DoF_ISM330DHCX.brd, SparkFun_6DoF_ISM330DHCX.sch]
2022-04-04 Completes routing, had to swap SDO and CS for ease of routing
    [SparkFun_6DoF_ISM330DHCX.brd, SparkFun_6DoF_ISM330DHCX.sch]
2022-04-04 Adds labels, fixes wonky box in schematic
    [SparkFun_6DoF_ISM330DHCX.brd, SparkFun_6DoF_ISM330DHCX.sch]
2022-04-04 Routes most of the micro board - I need to make space for lables on the underside.
    [SparkFun_6DoF_ISM330DHCX_Micro.brd, SparkFun_6DoF_ISM330DHCX_Micro.sch]
2022-04-04 Moves the i2c jumper
    [SparkFun_6DoF_ISM330DHCX_Micro.brd]
2022-04-04 Moves SDI_Aux and SDO_Aux jumpers to topside
    [SparkFun_6DoF_ISM330DHCX_Micro.brd]
2022-04-04 Moves fiducials back, cleans up some traces
    [SparkFun_6DoF_ISM330DHCX_Micro.brd]
2022-04-04 Adds labels to Mini
    [SparkFun_6DoF_ISM330DHCX_Micro.brd, SparkFun_6DoF_ISM330DHCX_Micro.sch]
2022-04-04 Adds Qwiic Micro
    * Given the nature of the design I was not able to get the board any smaller than a Qwiic mini, so I didn't bother routing it.
    [SparkFun_6DoF_ISM330DHCX_Qwiic_Micro.brd, SparkFun_6DoF_ISM330DHCX_Qwiic_Micro.sch]
2022-04-04 Adds a save point for Qwiic Micro - Revert here if removing SPI is not
    the way.
    [SparkFun_6DoF_ISM330DHCX_Qwiic_Micro.brd, SparkFun_6DoF_ISM330DHCX_Qwiic_Micro.sch]
2022-04-04 Removes Auxiliary pins to make the Qwiic Micro as Micro as possible
    [SparkFun_6DoF_ISM330DHCX_Qwiic_Micro.brd, SparkFun_6DoF_ISM330DHCX_Qwiic_Micro.sch]
2022-04-04 Adds measures
    [SparkFun_6DoF_ISM330DHCX_Qwiic_Micro.brd]
2022-04-04 Puts the three designs into folders
    [SparkFun_6DoF_ISM330DHCX.brd, SparkFun_6DoF_ISM330DHCX.sch, SparkFun_6DoF_ISM330DHCX_Micro.brd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]
2022-04-04 Updates labels on 1x1 to new SPI nomenclature,
    * moves pin1 indicator on IC closer to IC
    [SparkFun_6DoF_ISM330DHCX.brd, SparkFun_6DoF_ISM330DHCX.sch]
2022-04-04 Updates labels on Qwiic Micro, Updates IC on Qwiic Micro and Micro
    [SparkFun_6DoF_ISM330DHCX_Micro.brd, SparkFun_6DoF_ISM330DHCX_Micro.sch, SparkFun_6DoF_ISM330DHCX_Qwiic_Micro.brd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]
2022-04-06 Resizes and reroutes the Qwiic Micro board
    [SparkFun_6DoF_ISM330DHCX_Qwiic_Micro.brd, SparkFun_6DoF_ISM330DHCX_Qwiic_Micro.sch]
2022-04-06 Extends board to 0.75", adds better labels, adds 0402 LED to design
    [SparkFun_6DoF_ISM330DHCX_Qwiic_Micro.brd, SparkFun_6DoF_ISM330DHCX_Qwiic_Micro.sch]
2022-04-06 Moves some vias, fixes "x", "y", and "z" on axes, fixes some schematic typos
    [SparkFun_6DoF_ISM330DHCX.brd, SparkFun_6DoF_ISM330DHCX.sch]
2022-04-06 Fixes labels, realigns the SDX jumper on top
    [SparkFun_6DoF_ISM330DHCX_Micro.brd, SparkFun_6DoF_ISM330DHCX_Micro.sch]
2022-04-06 Moves resistor so that PWR silk is close to the LED
    * Fixes some trace bends
    [SparkFun_6DoF_ISM330DHCX_Qwiic_Micro.brd, SparkFun_6DoF_ISM330DHCX_Qwiic_Micro.sch]
2022-04-07 small adjustments
    [SparkFun_6DoF_ISM330DHCX_Qwiic_Micro.brd]
2022-04-08 Adds a new Qwiic Micro
    [SparkFun_6DoF_ISM330DHCX_Qwiic_Micro_Alternate.brd, SparkFun_6DoF_ISM330DHCX_Qwiic_Micro_Alternate.sch]
2022-04-08 Cams every design
    [SparkFun_6DoF_ISM330DHCX.GBL, SparkFun_6DoF_ISM330DHCX.GBO, SparkFun_6DoF_ISM330DHCX.GBP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]
2022-04-13 Fixes axes on bottom side incorrectly labeling the Z axis
    [SparkFun_6DoF_ISM330DHCX_Qwiic_Micro.brd, SparkFun_6DoF_ISM330DHCX_Qwiic_Micro_Alternate.brd]
2022-04-14 Fixes clearance issue with vias near 3v3 trace
    [SparkFun_6DoF_ISM330DHCX.brd]
2022-04-14 Removes pin numbers from ISM330DHCX symbol
    *Updates all designs to include the change which also included an update to the PROD_ID
    [SparkFun_6DoF_ISM330DHCX.brd, SparkFun_6DoF_ISM330DHCX.sch, SparkFun_6DoF_ISM330DHCX_Micro.brd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]
2022-04-18 Moves CS to top of symbol, moves VDD_IO to make space for SDA pin
2022-05-31 Removes unused size
    [SparkFun_6DoF_ISM330DHCX_Qwiic_Micro.GBL, SparkFun_6DoF_ISM330DHCX_Qwiic_Micro.GBO, SparkFun_6DoF_ISM330DHCX_Qwiic_Micro.GBP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]
2022-05-31 Removes proto gerbers, renames Qwiic_micro_alternate -> Qwiic_micro
    [SparkFun_6DoF_ISM330DHCX_Qwiic_Micro.brd, SparkFun_6DoF_ISM330DHCX_Qwiic_Micro.sch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]
2022-05-31 Fixes swapped silk on PICO and CS headers, changes to v10, adds "default" text to default address
    [SparkFun_6DoF_ISM330DHCX.brd, SparkFun_6DoF_ISM330DHCX.sch]
2022-05-31 Moves test points to their designated areas, increases the size of most of the silk
    * Moves to v10
    [SparkFun_6DoF_ISM330DHCX_Qwiic_Micro.brd, SparkFun_6DoF_ISM330DHCX_Qwiic_Micro.sch]
2022-05-31 Adds all the measures anyone could want
    [SparkFun_6DoF_ISM330DHCX_Qwiic_Micro.brd]
2022-06-01 adds 10k pullup on CS
    [SparkFun_6DoF_ISM330DHCX_Qwiic_Micro.brd, SparkFun_6DoF_ISM330DHCX_Qwiic_Micro.sch]
2022-06-02 Fixes silk for X-axis, changes tails on INT and GND silk
    [SparkFun_6DoF_ISM330DHCX_Qwiic_Micro.brd]
2022-06-02 Fixes some DRC errors
    [SparkFun_6DoF_ISM330DHCX_Qwiic_Micro.brd]
2022-06-02 Updates INT2 to rounded, and changes INT text on Micro to INT1
    [SparkFun_6DoF_ISM330DHCX.brd, SparkFun_6DoF_ISM330DHCX_Qwiic_Micro.brd]
2022-06-03 Adds a via, adds some clearer text to the schematic
    [SparkFun_6DoF_ISM330DHCX.brd, SparkFun_6DoF_ISM330DHCX.sch]
2022-06-03 Adds some text about i2c address and PTH connectors
    [SparkFun_6DoF_ISM330DHCX_Qwiic_Micro.sch]
2022-06-03 Removes old prototype gerbers and the "Micro" version
    [SparkFun_6DoF_ISM330DHCX.GBL, SparkFun_6DoF_ISM330DHCX.GBO, SparkFun_6DoF_ISM330DHCX.GBP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]
2022-06-03 Adds panel for Qwiic board
    [SparkFun_6DoF_ISM330DHCX-Panel.GBL, SparkFun_6DoF_ISM330DHCX-Panel.GBP, SparkFun_6DoF_ISM330DHCX-Panel.GBS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]
2022-06-03 Adds Qwiic Micro production files, moves them into their own folders
    [SparkFun_6DoF_ISM330DHCX-Panel.GBL, SparkFun_6DoF_ISM330DHCX-Panel.GBP, SparkFun_6DoF_ISM330DHCX-Panel.GBS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]
2022-06-08 Renames production files to include version number, updates 0402 RED LED with one that has PROD_ID
    [SparkFun_6DoF_ISM330DHCX.brd, SparkFun_6DoF_ISM330DHCX_Qwiic_Micro.brd, SparkFun_6DoF_ISM330DHCX_Qwiic_Micro.sch]

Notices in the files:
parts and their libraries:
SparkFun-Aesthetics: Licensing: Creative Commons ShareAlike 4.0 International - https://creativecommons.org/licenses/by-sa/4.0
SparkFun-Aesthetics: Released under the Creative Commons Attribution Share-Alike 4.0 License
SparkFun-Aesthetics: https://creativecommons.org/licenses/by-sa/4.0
